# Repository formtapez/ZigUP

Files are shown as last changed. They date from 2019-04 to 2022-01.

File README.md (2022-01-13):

# ZigUP
CC2530 based multi-purpose ZigBee Relais, Switch, Sensor and Router

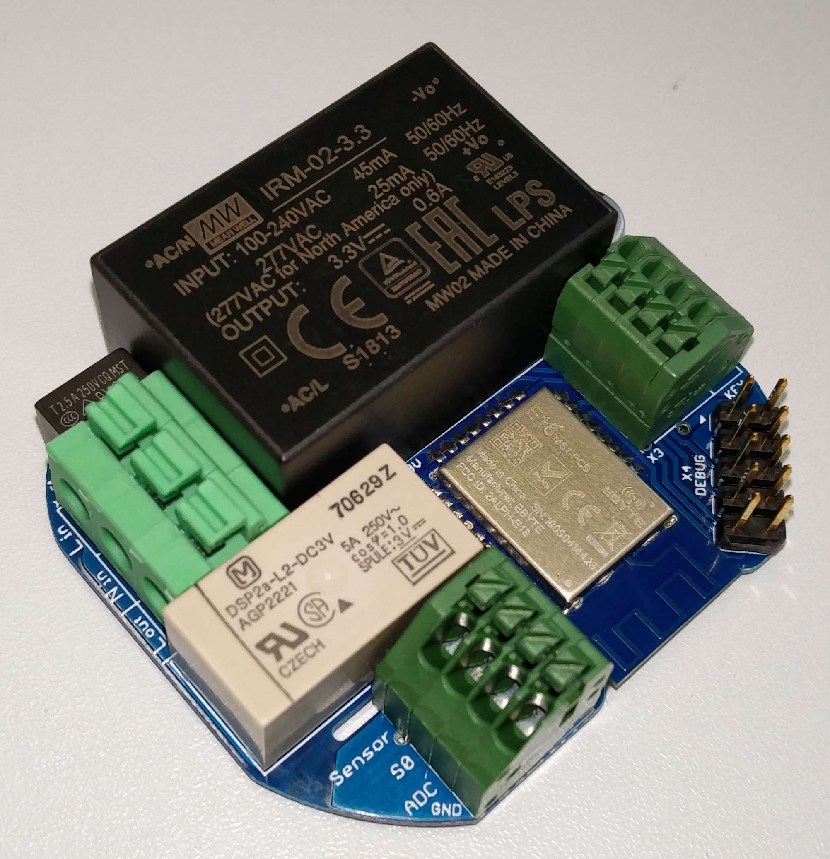
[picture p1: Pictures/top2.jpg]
Image of ZigUP board

[Bottom side](https://raw.githubusercontent.com/formtapez/ZigUP/master/Pictures/bottom.jpg)

# Features

* [Small enough to fit under a normal lightswitch](https://raw.githubusercontent.com/formtapez/ZigUP/master/Pictures/size.jpg) in an european flush-mounted box ("Unterputzdose" - That´s the UP in ZigUP)
* integrated optional ZigBee Router functionality (extends the range of all your other devices)
* Powerful bistable relais for up to 10 amps load
* 2 Inputs for switches/buttons:
	* Input "KEY" directly toggles the relais and outputs a ZigBee message
	* Input "DIG" only outputs a ZigBee message - So your coordinator can decide if the relais has to be toggled or not.
* Input for 16 digital temperature (DS18B20) and 1 humidity sensors (DHT22/AM2302) (Measurements will be reported via ZigBee)
* Input for S0-Bus impulses from power-, water- or gas-meters. Count-Value will be reported via ZigBee)
* Output for one normal LED or up to 10 WS2812B/Neopixel RGB-LEDs (controllable via ZigBee)
* Analog input to measure voltages of up to 32 Volt. (Voltage will be reported via ZigBee)
* Fully equipped debug-port to allow CC Debugger flashing and packet sniffing

# Connection diagrams

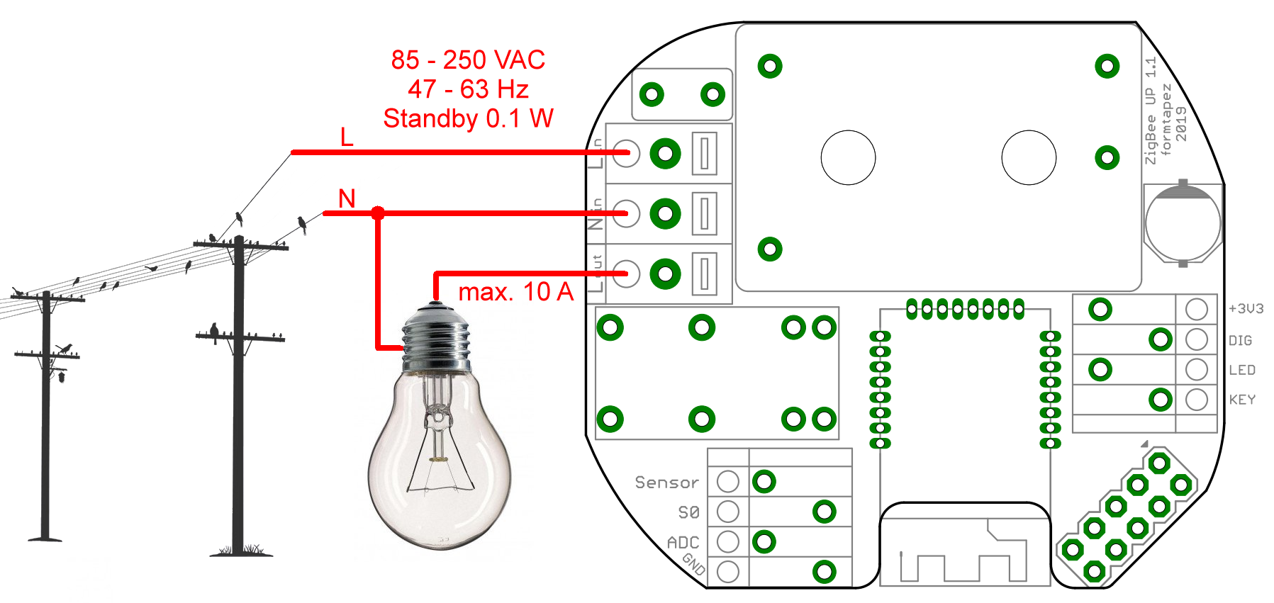
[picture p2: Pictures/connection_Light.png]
Power and Light connections

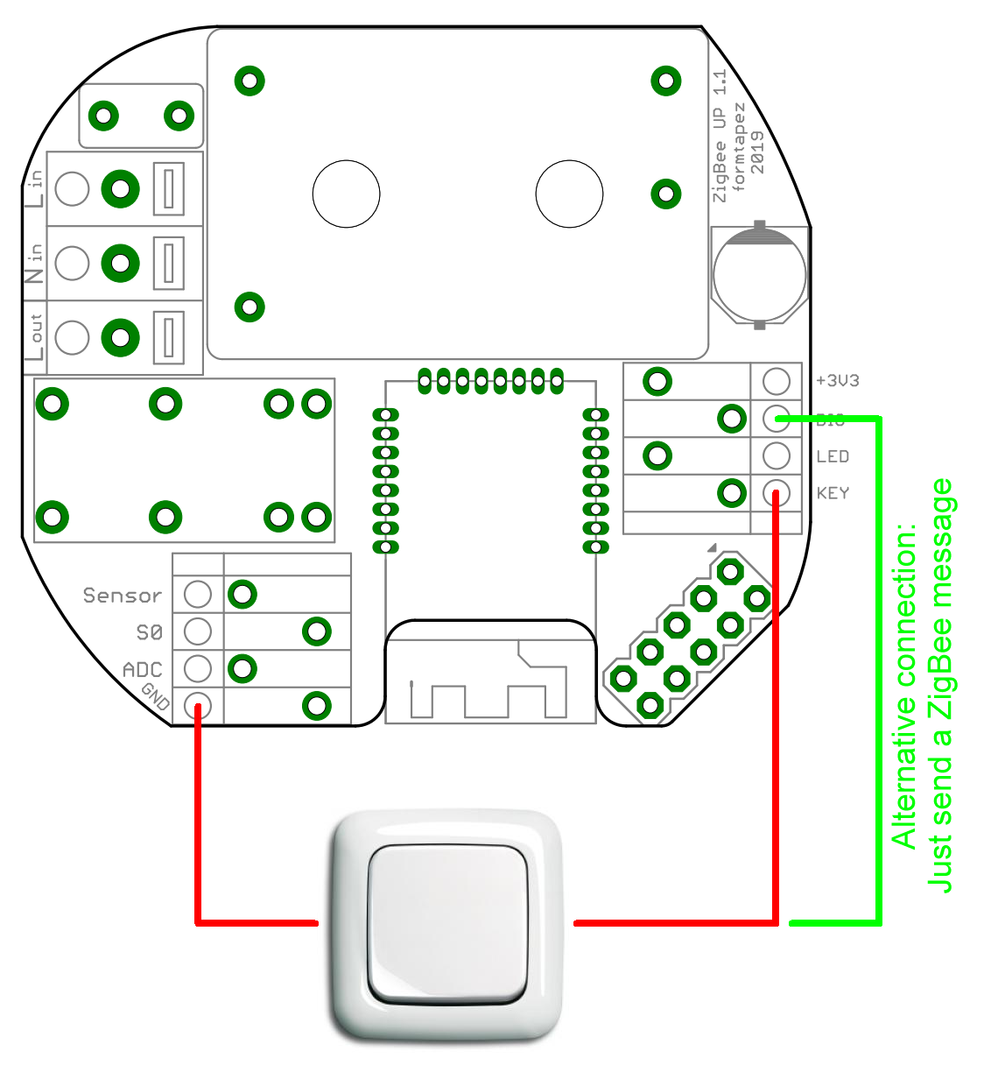
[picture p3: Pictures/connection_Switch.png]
Switch connections

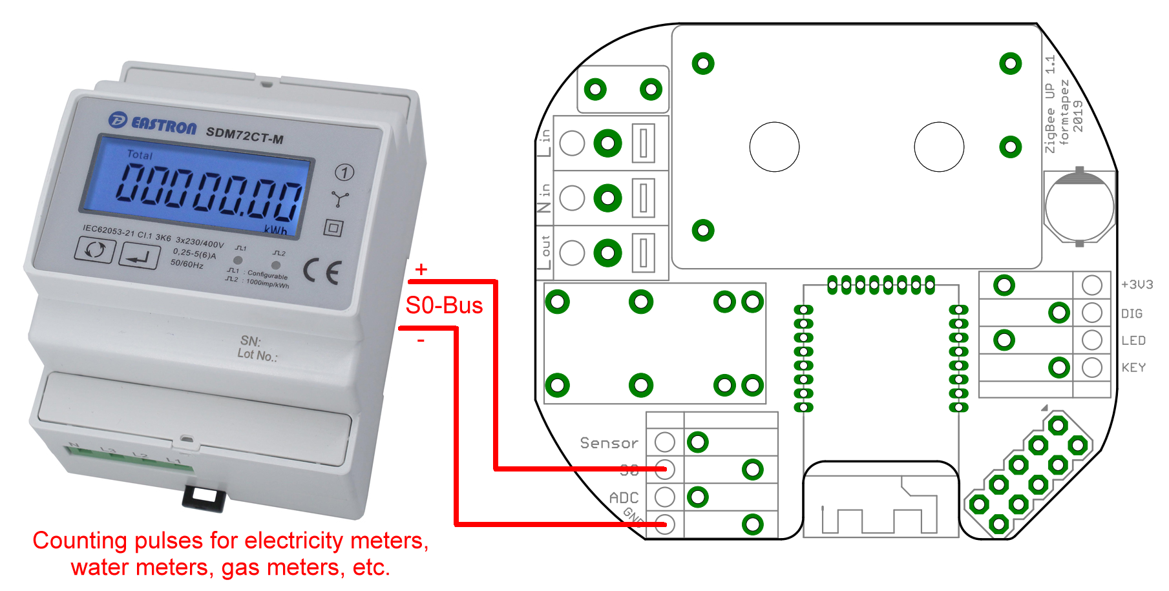
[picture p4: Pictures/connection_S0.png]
S0 connections

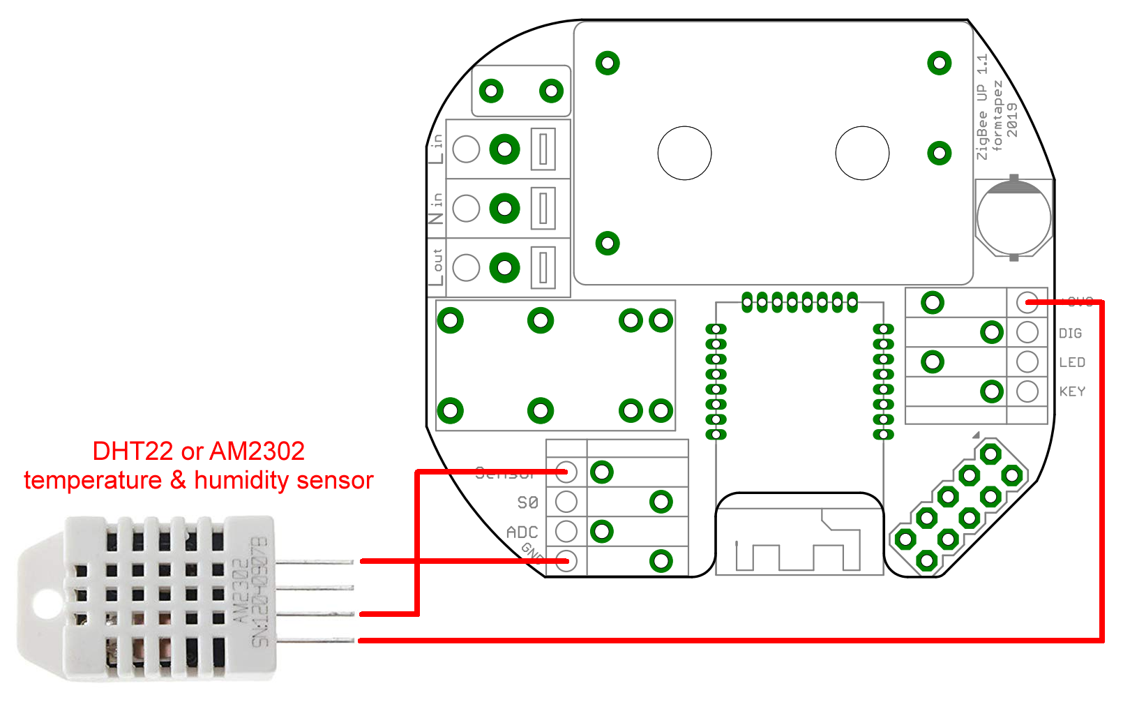
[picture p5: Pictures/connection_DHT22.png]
DHT22 connections

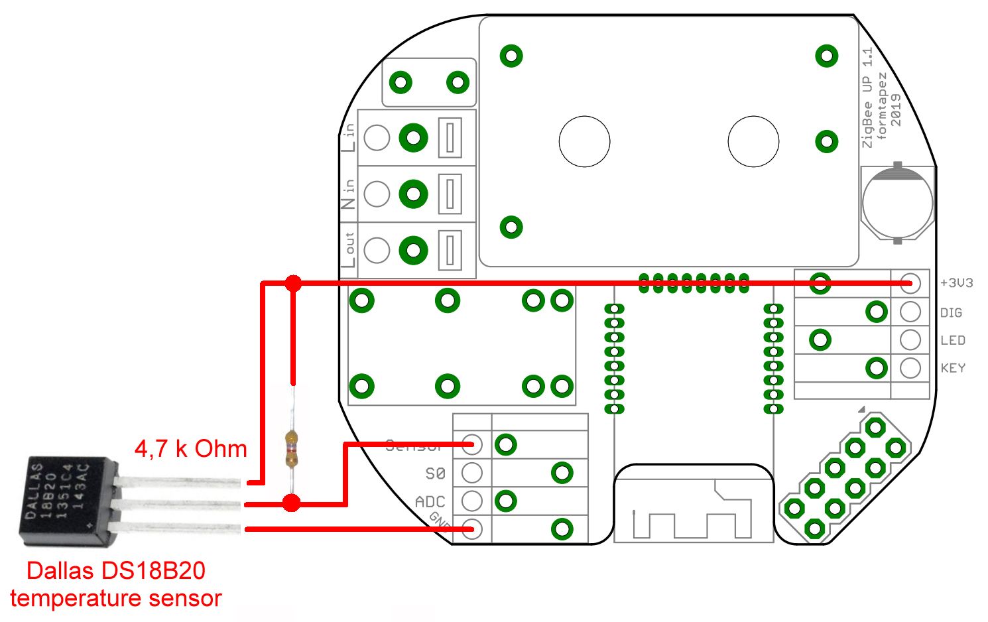
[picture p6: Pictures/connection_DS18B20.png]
DS18B20 connections

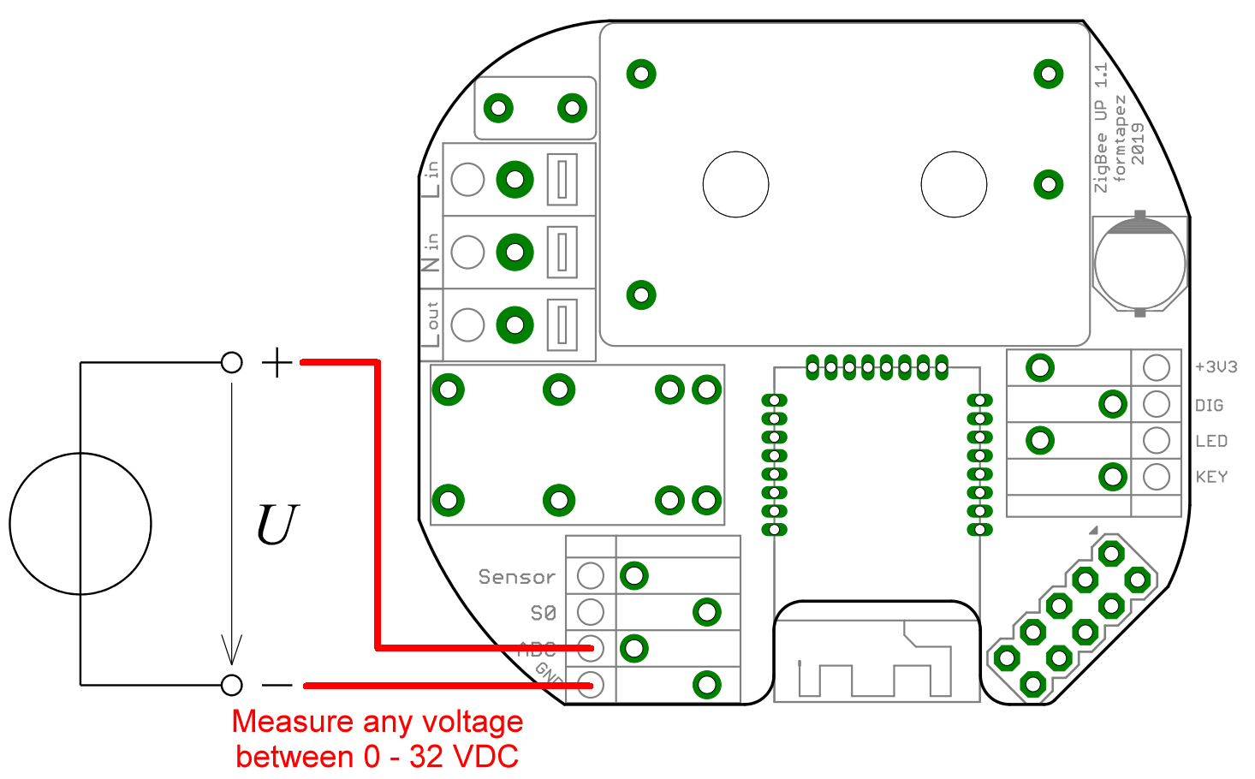
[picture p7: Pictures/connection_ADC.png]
ADC connections

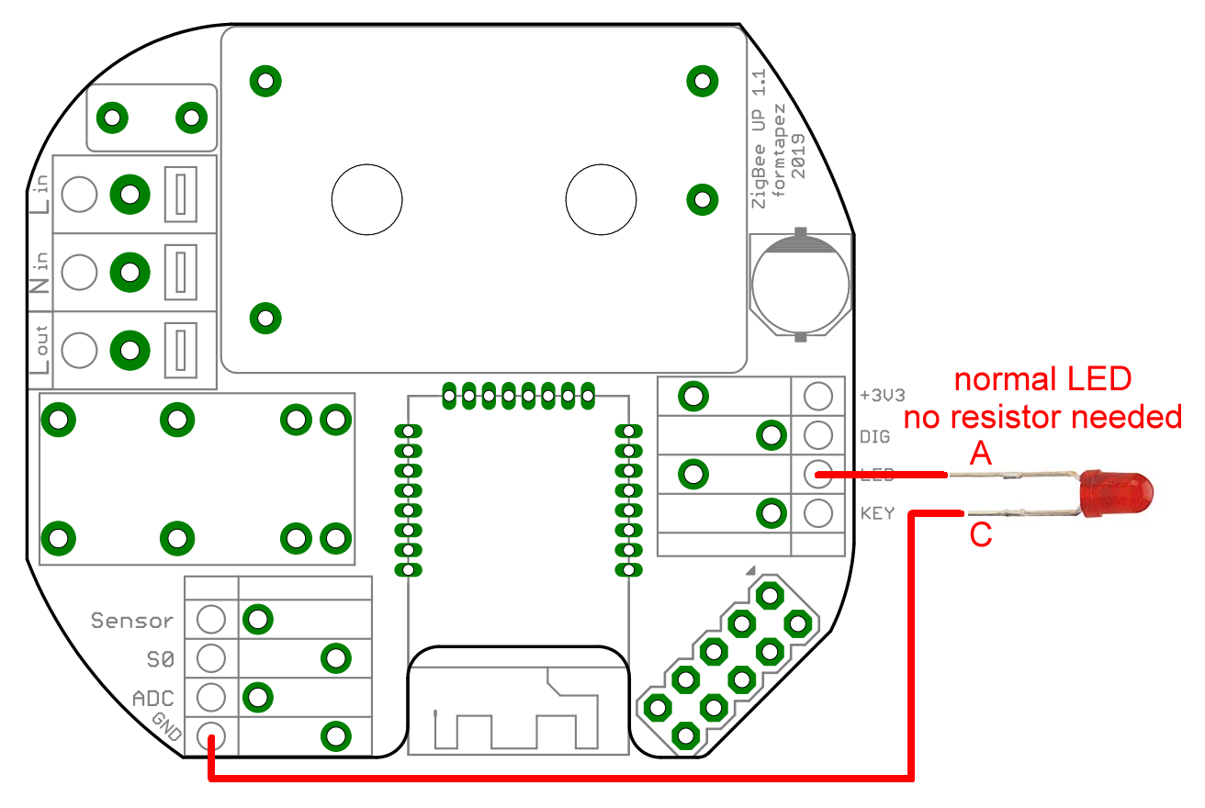
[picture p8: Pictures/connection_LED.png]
LED connections

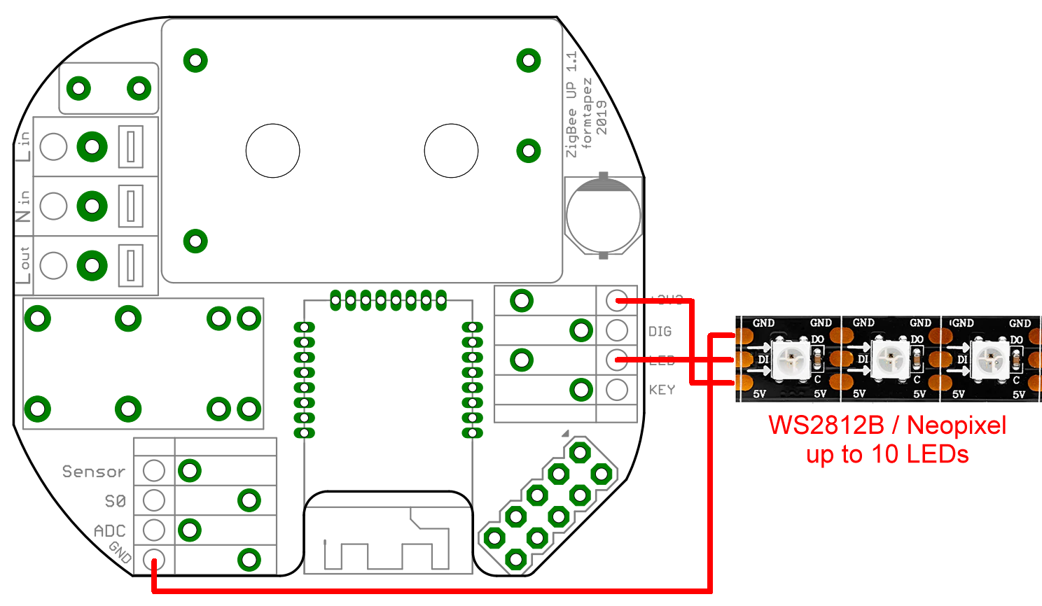
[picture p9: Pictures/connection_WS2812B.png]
WS2812B connections


# Compilation

1. Get **Z-Stack Home 1.2.2a.44539** from http://www.ti.com/tool/Z-STACK-ARCHIVE
2. Get **IAR Embedded Workbench for 8051** from https://www.iar.com/iar-embedded-workbench (you can use the free trial version for one month)
3. Clone ZigUP source to **\Projects\zstack\HomeAutomation\ZigUP\\**
4. Start **\ZigUP\CC2530DB\ZigUP.eww** to load project in IAR
5. Choose between **Router** and **EndDevice** configuration
6. Edit **\Projects\zstack\Tools\CC2530DB\f8wConfig.cfg** to select the ZigBee channel your coordinator is using.
7. Compile

# Flashing with CC Debugger
1. Get **SmartRF Flash Programmer v1.12.8 (not v2.x!)** from https://www.ti.com/tool/flash-programmer
2. Connect CC Debugger to the Debug-Port of ZigUP with an 1:1 cable.
3. Select "Program CCxxxx..." and "System-on-Chip" tab
4. Load HEX-File and perform "Erase, program and verify" action

# Packet Sniffing using CC Debugger
As an alternative usage of this board, it can be used as a ZigBee packet-sniffer in combination with the CC Debugger.
1. Get **PACKET-SNIFFER v2.18.1 (not SNIFFER-2 v1.x!)** from https://www.ti.com/tool/PACKET-SNIFFER
2. Connect CC Debugger to the Debug-Port of ZigUP with an 1:1 cable.
3. Select protocol "IEEE 802.15.4/ZigBee" and click "Start"
4. Change radio channel and click "Start"
5. Re-flash ZigUP firmware when you are done, because it was replaced by a sniffer-firmware.

# Bill of Materials (BOM)

Qty | Value | Package | Parts | URL (exemplary supplier)
:--:|:----- |:------- |:------|:------------------------
5 | 100 | R0805 | R1, R3, R5, R9, R10 | https://uk.farnell.com/multicomp/mcwr08x1000ftl/res-100r-1-0-125w-0805-thick-film/dp/2447552
1 | 1k | R0805 | R8 | https://uk.farnell.com/multicomp/mcsr08x102-jtl/res-1k-5-0-125w-0805-ceramic/dp/2074338
3 | 10k | R0805 | R2, R4, R6 | https://uk.farnell.com/multicomp/mcwr08x1002ftl/res-10k-1-0-125w-0805-thick-film/dp/2447553
1 | 27k | R0805 | R7 | https://uk.farnell.com/multicomp/mcwr08x2702ftl/res-27k-1-0-125w-thick-film/dp/2447620
2 | 100n | C0805 | C4, C5 | https://uk.farnell.com/multicomp/mcu0805r104kct/cap-0-1-f-50v-10-x7r-0805/dp/9406387
3 | 10µ | C0805 | C1, C3, C6 | https://uk.farnell.com/murata/grm21br61e106ma73l/cap-10-f-25v-20-x5r-0805/dp/2611941
1 | 220µ/6V3/EEEFK0J221P | PANASONIC_D | C2 | https://uk.farnell.com/panasonic/eeefk0j221p/cap-220-f-6-3v-radial-smd/dp/1850086
8 | 4148 | 1206 | D1 - D8 | https://uk.farnell.com/taiwan-semiconductor/ts4148-rxg/diode-small-signal-75v-0-15a-1206/dp/2708388
2 | IRFML8244 | SOT23 | T1, T2 | https://uk.farnell.com/infineon/irfml8244trpbf/mosfet-n-ch-25v-5-7a-sot23/dp/1857298
1 | IRM-02-3.3 | IRM-02 | IC1 | https://uk.farnell.com/mean-well/irm-02-3-3/power-supply-ac-dc-3-3v-0-6a/dp/2815480
1 | CC2530 | E18-MS1-PCB | IC2 | https://www.aliexpress.com/item/-/32803052003.html
1 | DSP2A-L2-DC3V | DSP2A-L2 | K1 | https://uk.farnell.com/panasonic-electric-works/dsp2a-l2-dc3v/relay-dpst-no-250vac-30vdc-5a/dp/2095635
1 | MST 2.5A 250V | MST | F1 | https://uk.farnell.com/multicomp/mst-2-5a-250v/fuse-radial-slow-blow-2-5a/dp/1566104
1 | Phoenix 1792876 | PTS-3 | X1 | https://uk.farnell.com/phoenix-contact/1792876/terminal-block-wire-to-brd-3pos/dp/2072378
2 | TE 1-2834021-4 | MSC4 | X2, X3 | https://uk.farnell.com/te-connectivity/1-2834021-4/tb-wire-to-board-4pos-26-20awg/dp/2610379
1 | DEBUG | MA05-2 | X4 | https://uk.farnell.com/amphenol-icc-fci/67997-210hlf/connector-header-10pos-2row-2/dp/2886080
1 | PCB | FR4 | all | Use [Gerber files](https://github.com/formtapez/ZigUP/tree/master/Layout/Gerber) or contact me if you need a bare PCB

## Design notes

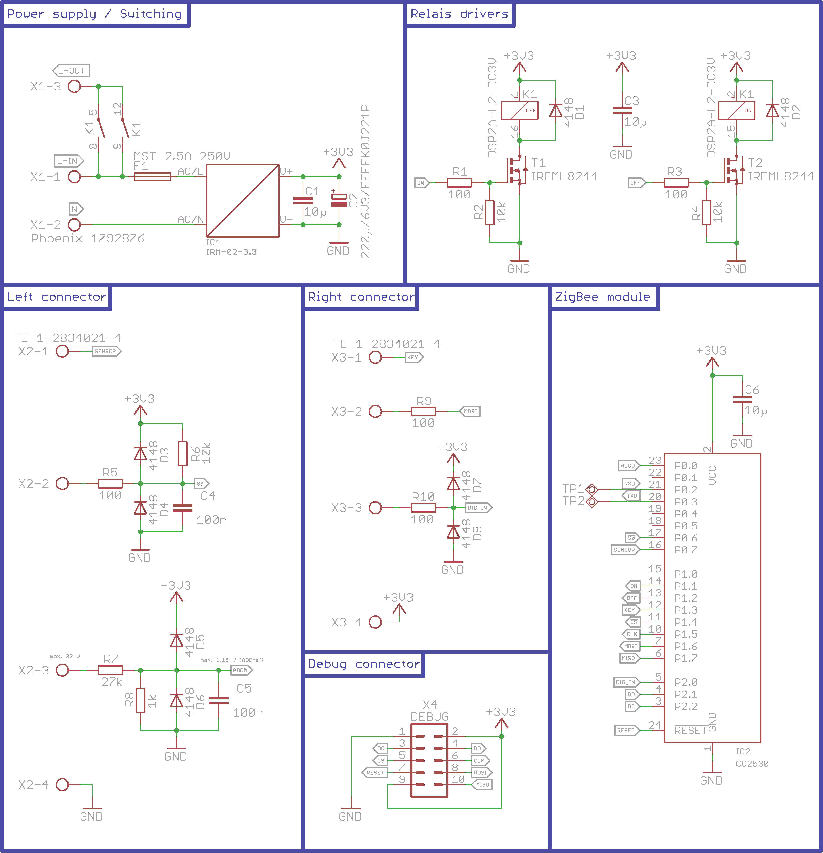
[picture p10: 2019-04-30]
Layout/Images/schematic.png

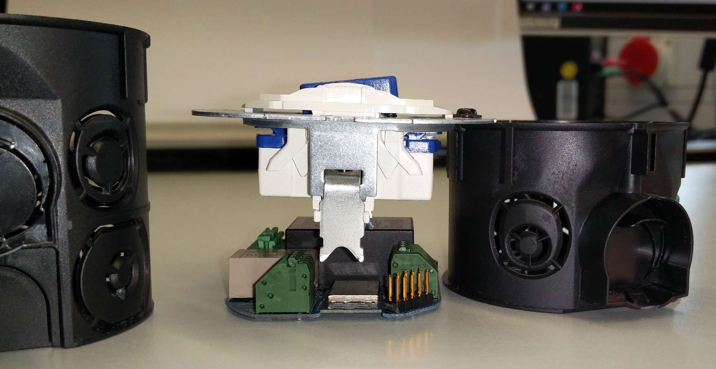
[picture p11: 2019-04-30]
Pictures/size.jpg

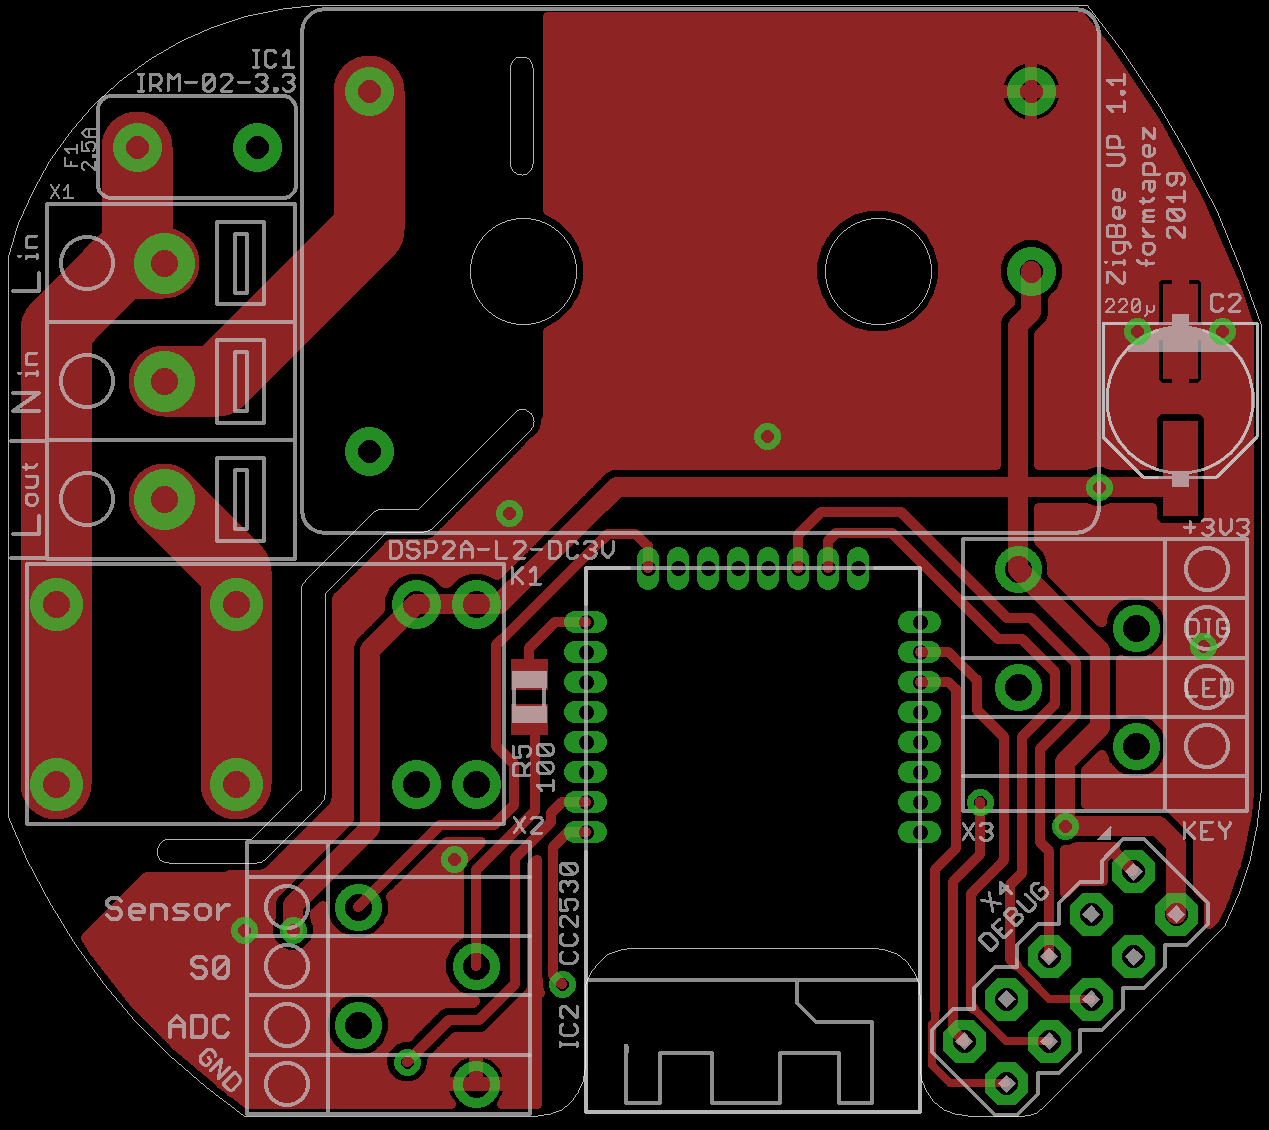
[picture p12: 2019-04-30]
Layout/Images/top.png

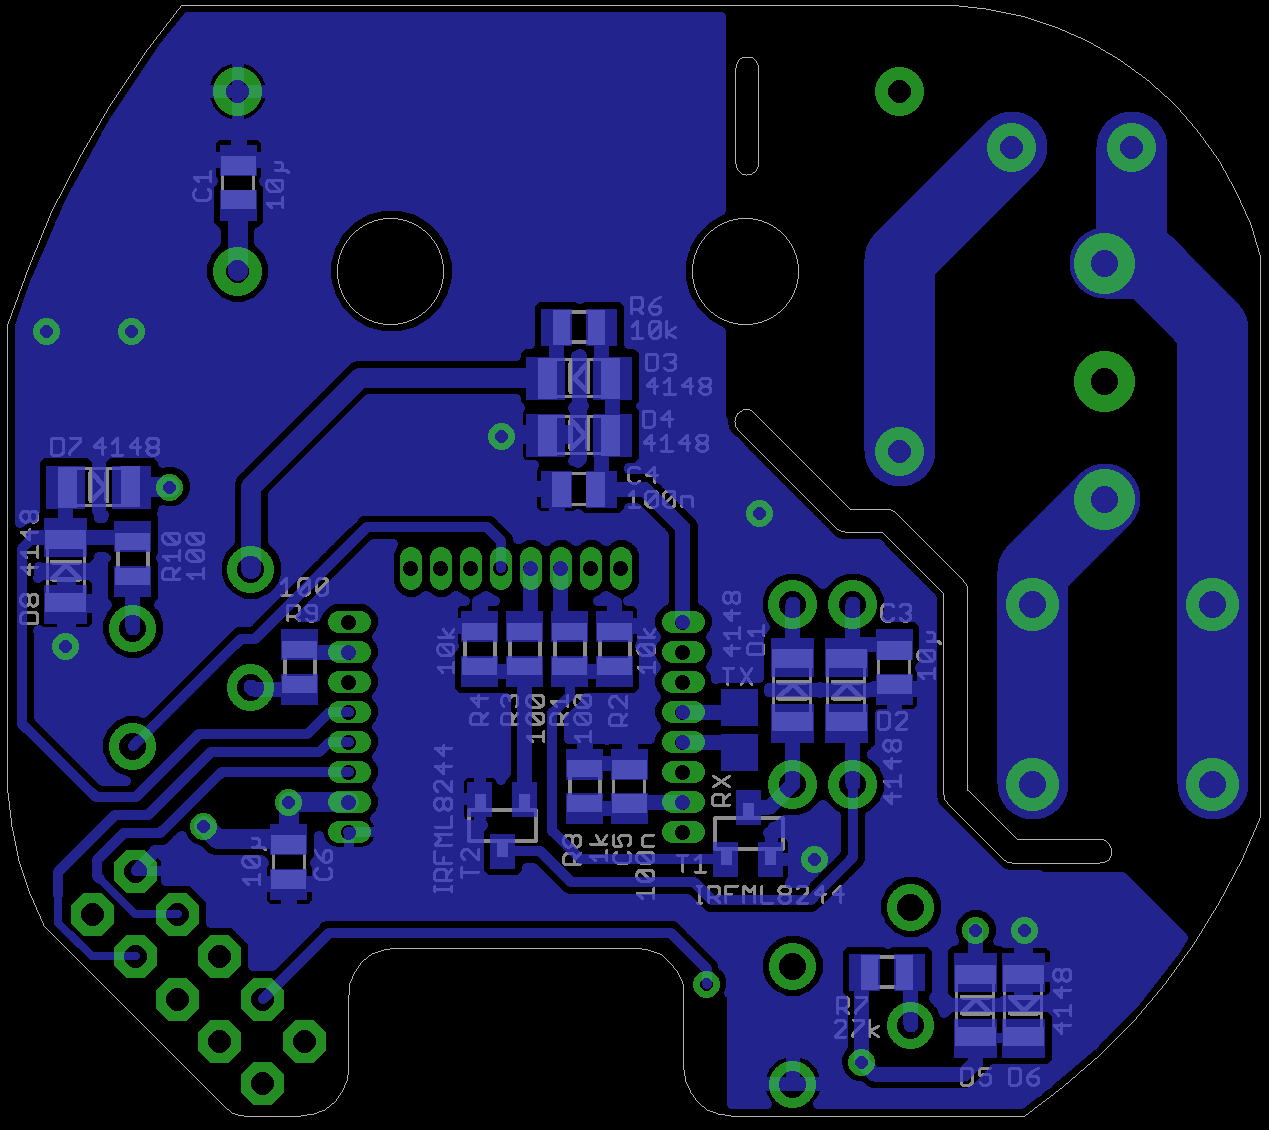
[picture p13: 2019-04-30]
Layout/Images/bottom.png

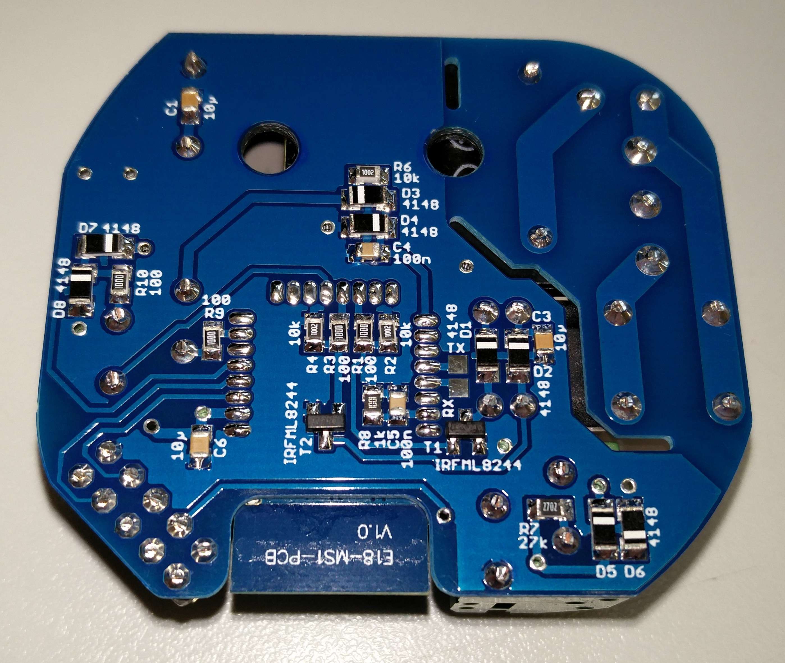
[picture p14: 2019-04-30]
Pictures/bottom.jpg

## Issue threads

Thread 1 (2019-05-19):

Where to get?

ryanbeaton, 2019-05-19:
Brilliant project!
Where to get hardware?
Will they be sold assembled?

formtapez, 2019-05-19:
Hi.
I'm not selling the hardware but you can get bare PCBs from me if you want to build it yourself.
I've added a [Bill of materials](https://github.com/formtapez/ZigUP#bill-of-materials-bom) to the end of the README.md file where you can find sellers for every component and contact info to get bare PCBs.

ryanbeaton, 2019-05-23:
Thanks
I’m not a that proficient at soldering so it’s not for me unfortunately.
If you do start selling them let me know.

h4nc, 2019-07-16:
Hi,

very interessting product. It's like a Zigbee Allrounder.

I have some soldering skills and I'm considering making some of these.

I already offer ready2use zigbee2mqtt sticks.

See https://community.home-assistant.io/t/buy-a-ready2use-zigbee2mqtt-stick-flashed-antenna-mod-and-printed-case/111743

@formtapez Would you be fine with me offering these? Currently I cannot tell how much time it would take me to make one of these, so maybe it would get to expensive for users anyway.

formtapez, 2019-07-16:
@h4nc sure, sell them if you like. Let me know when you need PCBs :)
But maybe you should wait some time for a cost-reduced version mentioned in #3

h4nc, 2019-07-16:
Thank you. A cheaper version would be great (or necessary to make it interessting for people). I will probably make some suggestions in that other issue.

aryehassbian, 2020-09-13:
> Hi.
> I'm not selling the hardware but you can get bare PCBs from me if you want to build it yourself.
> I've added a [Bill of materials](https://github.com/formtapez/ZigUP#bill-of-materials-bom) to the end of the README.md file where you can find sellers for every component and contact info to get bare PCBs.

That looks interesting..
Do you have Gerber file for download?
Thanks

formtapez, 2020-09-13:
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

Yes, check out https://github.com/formtapez/ZigUP/tree/master/Layout/Gerber

darekhome, 2020-12-25:
Hi - possible to buy somewhere the PCB with at least 'smd' parts assembled...?

Closed 2020-01-15.

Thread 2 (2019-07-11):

It is perfect

freenetwork, 2019-07-11:
You have a great project. However, I wanted to learn how to program the TI CC2530 myself. Tell me how did you study? Very heavy entry.

freenetwork, 2019-07-11:
This relay Can it be attached to a conbee?

formtapez, 2019-07-11:
For flashing you can use a "CC Debugger" device. Described here: https://www.zigbee2mqtt.io/getting_started/flashing_the_cc2531.html
Or you can use an Arduino or Raspberry Pi:
https://www.zigbee2mqtt.io/information/alternative_flashing_methods.html

I don't know the "Conbee" device, but it seems it was build to pair with custom devices. So i would assume it should work.

Closed 2019-08-29.

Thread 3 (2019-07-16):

Alternative/Cheaper components

sebastianhodapp, 2019-07-16:
Dear @formtapez

first of all: Kudos for this masterpiece of work! This versatile device looks like a perfect fit for so many possible applications!

When calculating and planning to build a batch myself, it looks like the relay and the PSU are really cost drivers. Have you had a look into alternative components?

For the PSU the HLK-PM03 could be a replacement with the same form factor, but less than 2,5$: https://www.mikrocontroller.net/attachment/349613/HLK-PM03.pdf

For the relay, I haven't found one wit the same dimensions (yet), but if the jqc3f-03vdc-c (https://voron.ua/files/pdf/relay/JQC-3F(T73).pdf) could be squeezed on the board, it would be a killer (from pricing perspective with <0,5$)

BR,
Sebastian

formtapez, 2019-07-16:
Hi,
you are right, these two components are really not cheap.

I chose the Meanwell power supply for safety reasons. For something which is on mains 24/7 even when nobody is at home, i really dont like to have such HiLink module. But a dual-footprint on the pcb to still have the option would be a smarter idea.

The relay choice was not very clever, because i wanted a bistable one to safe standby-power. This in combination with only 3,3 Volt and a high switching current limited the selection possibilities on the market and drove the price up. When you try to squeeze another relais on the boards, you should take a bistable relais, too. For a normal monostable relais you have to patch the firmware.

I will make a improved board layout in some time in which these points get cleared.

h4nc, 2019-07-16:
Would be great to make it as cheap as possible (while keeping it safe of course).

So first it would lower the cost if we could use parts that are available at aliexpress (no shipping cost and cheap prices). Most of the SMD are available there but I don't know if the the cable sockets are available too. The sonoff basic is a very low cost product. Maybe you use parts they are using (relay, power supply, should be cheap and save).

Another sugestions is to use the same pinheader as the CC2531 Sticks use. It's smaller and most zigbee2mqtt flashers have that cable.
https://de.aliexpress.com/item/32972376101.html?spm=a2g0s.9042311.0.0.27424c4dKMNl5m

I hope I can get back to you when I have more ideas. Those are only suggestions.

Thanks!

h4nc, 2019-07-16:
Another idea would be to make a second version that is able to dimm lights.

Or maybe it’s possible to include that in one version. So it’s able to only switch on/off or dimmable.
There are Tuya dimmers out there that could help finding the right parts for that.

sebastianhodapp, 2019-07-17:
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

As I would only install them into some garden lights, I wouldn't be concerned. But inside at home, makes totally sense.

> The relay choice was not very clever, because i wanted a bistable one to safe standby-power. This in combination with only 3,3 Volt and a high switching current limited the selection possibilities on the market and drove the price up. When you try to squeeze another relais on the boards, you should take a bistable relais, too. For a normal monostable relais you have to patch the firmware.

I must admit, I missed that detail in the datasheet. I like your design now even more, knowing that you though even about standby-power! But true. Limits the available products significantly. I'll keep an eye open.

> I will make a improved board layout in some time in which these points get cleared.

Wow, thanks!

eddso, 2019-08-09:
First of all, very nice project, i like it, great work.
Here my suggestion for cheaper component relay:
https://lcsc.com/product-detail/Relays_HF163F-L-3-HL2T_C140724.html?currency=EUR
https://german.alibaba.com/product-detail/HF163F-L-3-HL2T-Pushbutton-Switches-60829718344.html

formtapez, 2019-08-29:
I like your second single-coil relais. It is cheap and small (the first one is too high if you want to install the board behind a wallswitch).
But that relais only has switching capacity of up to 60 watt - That can be too weak if you still have some lightbulbs somewhere.

h4nc, 2019-09-10:
@formtapez are you still planning to do a second version with cheaper components?

formtapez, 2019-09-11:
@h4nc Yes, but it is not very high on my priority list :(

martcs, 2019-12-10:
@formtapez do you still offer ZigUp pcb?  If yes than what cost it?

formtapez, 2019-12-10:
@martcs yes. Use contact-info in last line of [README.md](https://github.com/formtapez/ZigUP/blob/master/README.md) and tell me destination country and amount of PCBs, so i can calculate a price.

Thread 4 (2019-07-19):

illuminance sensor

anshgh, 2019-07-19:
Hi
Can I make a light sensor (illumination) with a BH1750?

formtapez, 2019-07-19:
The processor doesnt have a TWI interface, so its not possible.
But you can use an analog sensor like a photoresistor or solar-cell on the analog-input pin.

anshgh, 2019-07-19:
Tanks.
I need high resolution illuminance. Because my sensor Aqara Motion Sensor gives a maximum of 1000 Lx and in cloudy and sunny weather.
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
Do you know the illuminance sensor with WTI support?

anshgh, 2019-07-22:
Which pins of the CC2530 (P00-P22) correspond to the pins on your board (Sensor, S0, ADC, DIG, LED, KEY)?

formtapez, 2019-07-22:
Just have a look in the [schematic](https://raw.githubusercontent.com/formtapez/ZigUP/master/Layout/Images/schematic.png).

anshgh, 2019-07-22:
Tanks.
Can I buy such a module on Aliexpress?
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

anshgh, 2019-07-23:
or - https://ru.aliexpress.com/item/32982000600.html

formtapez, 2019-07-23:
These are no illumination sensors. But if you want to measure rotation angle, you can use them.

anshgh, 2019-07-23:
Yes. I know. This is a variable resistor to replace (not solder) the element X2-3 to ADC0. https://user-images.githubusercontent.com/8523569/61642187-2a431280-aca9-11e9-967b-9c66f99e5a8b.png

I want to use the TEMP6000 light sensor. He is 5 volt. But in your circuit to ADC0 you need 1.15 volts. Therefore, I want to use a variable resistor (links above) to connect the TEMP6000.

formtapez, 2019-07-23:
I dont think that works. The current is too low to drive the ADC. You need an active component there.

anshgh, 2019-07-23:
Why? It works for me on esp8266.

anshgh, 2019-07-23:
Can you help turn on the deep sleep mode for the CC2530 for 2 minutes in your firmware?

anshgh, 2019-07-26:
> The processor doesnt have a TWI interface, so its not possible.
> But you can use an analog sensor like a photoresistor or solar-cell on the analog-input pin.

https://e2e.ti.com/support/wireless-connectivity/zigbee-and-thread/f/158/p/824148/3049477#3049477

anshgh, 2019-08-12:
> The processor doesnt have a TWI interface, so its not possible.
> But you can use an analog sensor like a photoresistor or solar-cell on the analog-input pin.

I want to use a TEMP6000 sensor.
How often will data from analog sensors be transmitted?
Can I change this time?

formtapez, 2019-08-12:
You can change the reporting interval (default: 30s) here:
https://github.com/formtapez/ZigUP/blob/ec3112c4933cfd9b377bc32b3dd97cde0bd6086c/src/ZigUP/Source/zcl_zigup.c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

anshgh, 2019-08-14:
What is **adc_volt":2.259**? I connected TEMP6000 3.3v.
 zigbee2mqtt:info 8/14/2019, 3:16:25 PM MQTT publish: topic 'zigbee2mqtt/0x00124b001d6663ed', payload '{"state":"OFF","cpu_temperature":24.48,"external_temperature":null,"external_humidity":null,"s0_counts":0,"adc_volt":2.259,"dig_input":1,"reason":"timer","linkquality":134}'

formtapez, 2019-08-14:
that seems pretty correct for me.
you can measure up to 32 volt due to that resistor-divider at the input.

anshgh, 2019-08-20:
What you need to enable sleep mode (PM2).
"**You can define POWER_SAVING in project predefined symbols to enable it. After you define POWER_SAVING, CC2530 will enter sleeping mode automatically when there’s nothing in osal task queue.**"
Enable a compile option, del an "x" at the left edge of the line or add POWER_SAVING.

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

Awakening interval can be configured in the file zcl_zigup.c :
`#define ZIGUP_REPORTING_INTERVAL 120000 (120sec)`

Other than report interval, polling rate would wake up device every second by default.
You can change polling rate by changing -DPOLL_RATE in f8wconfig.cfg.

anshgh, 2019-09-23:
I also changed the code in zcl_zigup.c to turn off the voltage of the TEMP6000 sensor during sleep mode.
I connected TEMP6000 to 3.3v = P1.6 and data = P0.0
added:
`    // update measurements
    LED(1);
    _delay_ms(1000);
    Measure_QuickStuff();
    Measure_Sensor();
    LED(0);`

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

commented:
`    //LED(1);`
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

Closed 2019-08-14.

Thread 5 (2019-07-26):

PWM Support ?

michaelslobodskih, 2019-07-26:
Is it possible to add 2 x channel PWM support to firmware ?

formtapez, 2019-07-29:
Technically, that's possible.

https://github.com/formtapez/ZigUP/blob/master/Datasheets/CC2530%20User%20Guide.pdf
Look at table on page 81 to find a pin for a timer compare output pin, which was unused before.

michaelslobodskih, 2019-07-29:
Nice, so can u add pwm support to your firmware ?

formtapez, 2019-07-29:
I don't know that yet.
Do you have a good use-case for that? What do you want to control, and how?

michaelslobodskih, 2019-07-29:
I have led lamp controller by rc protocol . Inside this lamp there is one little pcb with 4 pins ( +,- , A, B). Channel A & B is pwm , 0-3.3v.

I installed esp8266 and all works fine with additional power supply (AC to DC 3.3 500mah).

And i have iobroker smart home  with ~ 10 zigbee devices.

So i'm intresting to replace esp8266 & power supply (is overhead for this project) with only 1 module based on cc253x.

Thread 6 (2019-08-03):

Multiple ds18b20 sensors

prelude0000, 2019-08-03:
Hello,

I added support for multiple (16 currently) 1-wire temperature sensor in this great code. It's work's fine but before i can make a merge request i need to understand how to inform zigbee2mqtt that devise have multiple sensors.

I can add use the same idea of how current sensors/peripherals are defined in zcl_zigup.c but it causes a problem when a new sensor is added and sensor order will be chances

Example there is 3 sensor and zigup sending to zigbee2mqtt following message:
 '{
"state":"OFF",
"cpu_temperature":23.98,
"external_temperature_1":21.4, // device 4D000004D0DC8328
"external_temperature_1":22.4, // device B1000004D01FBF28
"external_temperature_3":23.4, // device C000004D03CA328
"external_temperature_4":-1000,
"external_temperature_5":-1000,
...
"external_temperature_16":-1000,
"external_humidity":null,
"s0_counts":0,
"adc_volt":32.354,
"dig_input":1,
"reason":"timer",
"linkquality":23
}'

and when we add one new sensor (4 total) then important part would be:
"external_temperature_1":21.4, // device 4D000004D0DC8328
"external_temperature_2":24.4, // device A1000004D05ABF28
"external_temperature_3":22.4, // device B1000004D01FBF28
"external_temperature_4":23.4, // device C000004D03CA328
"external_temperature_5":-1000,

so sensor order what you see in zigbee2mqtt is mixed (old sensor_2 is now sensor 3)

One way to solve this is to send sensor id and temperature at the same time like this:
"4D000004D0DC8328":21.4,
"B1000004D01FBF28":22.4,

and if zigbee2mqtt do not support dynamically added devices then send dummy code for sensor what aren't connected like "0000000000000000":-1000.

As you see, i don't really know how to proceed and i would appreciate every guide/hint what you can give me to make code nice and compatible with zigbee2mqtt philosophy.

formtapez, 2019-08-29:
Looking at your pullrequest #9 it seems you found a solution meanwhile. So i'll close here.
(I'll review your PR in the next few days)

Closed 2019-08-29.

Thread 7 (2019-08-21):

Improve detail on how to flash HEX files

daparix, 2019-08-21:
I just build/soldered my first unit, and running following issues:
- Not sure of the polarity of the 10-pin programming connector. I understood it should be with red wire (pin 1) on the far side of the RF board (close to the connector of KEY/LED/DIG).

- I had to file one corner of the connector of the CC debugger cable before I could make it fit. Is this normal?

- It would be nice if there is some guideline to flash units with a default HEX file (I found it in another repository, but would be good to have default hex files here so compiling is not needed).

- As a bonus, would be great to have a guide to flash them using Ubuntu (i.e with cctool). I have found some bits of info, but as the default Windows flashing does not work, I do not dare to try a Linux flash yet.

PD: Not really in the main request as this part is not generic, but I can not flash the hex and would need some help:
The CC debugger shows red led when I do not connect the ZigUP and SmartRF Studio detects it right. If I plug the CC debugger with ZigUP connected, led shows off (and USB does not detect the CC debugger). Do I need to power ZigUP as well to 220V or it maybe some problem with my soldering - I just took a snapshop if someone can confirm it is right?

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

daparix, 2019-08-21:
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

daparix, 2019-08-21:
None: Just realized the HEX files can be got from "Releases" tab, but I meant to have the HEX files as part of the source tree as well for those users that are not very expert with GitHub

formtapez, 2019-08-21:
Hi, please do not connect 220 Volts in this state - It is way too dangerous.
Powering via CC-Debugger is totally okay for programming.

It seems you have a short somewhere between GND and +3V3, when your Debugger-LED went off when plugging in. Can you measure resistance between this two signales?

Your polarity of the connector is right, and yes, it is very tight to the connector nearby.

daparix, 2019-08-22:
thanks for all the feedback!

indeed I have a short between 3.3V and GND. I tried visually and resoldered a couple of components, but I have still not fixed it, so will need to allocate more time. will come back as I progress on this, maybe I try a second unit mount (step by step) to progress on this, as I guess will be quicker/easier than finding the wrong solder or component in my first unit.

great work done by you!

daparix, 2019-09-09:
Sorry to have delayed so much, I have too many projects in queue!!.
Built a second unit checking carefully each component soldering as I mounted them and I got a working one. Resistance between 3.3V and GND is around 4.5Kohm.

This one properly connects via CC_Debugger and I got a nice green led light, so ready to be programmed.

Many thanks!

Closed 2019-08-29.

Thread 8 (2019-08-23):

GB2530 - Different Module

YeisonCL, 2019-08-23:
Hi,

First of all, kudos for this project, it is really incredible!

I have a quick question.

Is it possible to use a different module for this project? I noticed you used E18-MS1-PCB module for this project. I have a GB2530 module: [GB2530 Module](http://www.gban.cn/en/product_show.asp?id=47)

This module includes the CC2530 + RFX2401, can I use this module instead of  E18-MS1-PCB?

Thanks!

formtapez, 2019-08-23:
Hi,
this module does not fit on the board, the footprint and pinout is different and you would have to include the controlling of the integrated RF-amplifier into the software.

Closed 2019-08-23.

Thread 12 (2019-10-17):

Reset

copystring, 2019-10-17:
Is there a way to reset the pairing and re-pair?
I assume I have to flash this again to re-pair.
Or is there another way?

formtapez, 2019-10-18:
If you have connected a button to the "key" input, you can press it for 5 seconds to initiate re-pairing.
Also when you turn off you coordinator so ZigUp is loosing connection, it enters re-pairing mode.

copystring, 2019-10-18:
OK. Hold the button seems to initiate re-pairing. The relay clicks off and on quickly. Assuming it worked it does not re-enter my network. I have changed the  channel of my network to 13 and changed the pan_id as well.
Does that matter?

formtapez, 2019-10-18:
Depends on which firmware you flashed. The precompiled hex files from the Release-section is fixed to channel 25.

copystring, 2019-10-18:
Right. Changed back to channel 11. It works now with the precompiled firmware. Why do you say it is channel 25? It is channel 11. Am I missing something here?

formtapez, 2019-10-18:
With "precompiled firmware" i mean the hex-files from the "release" section here on github.
I compiled them with
`-DDEFAULT_CHANLIST=0x02000000  // 25 - 0x19`
in zstack\Tools\CC2530DB\f8wConfig.cfg

The default there is channel 11. Did you compiled it yourself?

copystring, 2019-10-18:
Nope. I am using the precompiled version. Could not be bothered to install all the tools.

Closed 2019-10-19.

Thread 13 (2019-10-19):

Cannot read property '41368' of undefined

copystring, 2019-10-19:
Not sure if this is an issue with ZigUP or z2m. Let me know if it does not belong here.

I am getting a lot of this:

```
Oct 19 11:17:12 raspberrypi npm[9723]: zigbee2mqtt:error 2019-10-19T09:17:12: Failed to call 'DeviceReceive' 'onZigbeeEvent' (TypeError: Cannot read property '41368' of undefined
Oct 19 11:17:12 raspberrypi npm[9723]:     at Object.convert (/opt/zigbee2mqtt/node_modules/zigbee-herdsman-converters/converters/fromZigbee.js:1353:30)
Oct 19 11:17:12 raspberrypi npm[9723]:     at converters.forEach (/opt/zigbee2mqtt/lib/extension/deviceReceive.js:146:41)
Oct 19 11:17:12 raspberrypi npm[9723]:     at Array.forEach (<anonymous>)
Oct 19 11:17:12 raspberrypi npm[9723]:     at DeviceReceive.onZigbeeEvent (/opt/zigbee2mqtt/lib/extension/deviceReceive.js:144:20)
Oct 19 11:17:12 raspberrypi npm[9723]:     at Controller.callExtensionMethod (/opt/zigbee2mqtt/lib/controller.js:320:44)
Oct 19 11:17:12 raspberrypi npm[9723]:     at Controller.onZigbeeEvent (/opt/zigbee2mqtt/lib/controller.js:228:14)
Oct 19 11:17:12 raspberrypi npm[9723]:     at Zigbee.emit (events.js:198:13)
Oct 19 11:17:12 raspberrypi npm[9723]:     at Controller.herdsman.on (/opt/zigbee2mqtt/lib/zigbee.js:56:52)
Oct 19 11:17:12 raspberrypi npm[9723]:     at Controller.emit (events.js:198:13)
Oct 19 11:17:12 raspberrypi npm[9723]:     at Controller.<anonymous> (/opt/zigbee2mqtt/node_modules/zigbee-herdsman/dist/controller/controller.js:405:22))
```

Looking at the code of z2m it seems it does that with the precompiled firmware since it does not have the temp sensor connected?

formtapez, 2019-10-19:
Property '41368' is a newer way of reporting DS18B20 sensors. It is used even if you have no sensors. Support for that is merged into Zigbee2MQTT source, but it seems that it hasn't reached into the "stable" channel yet.
You can manually update this file just by replacing it:
https://github.com/Koenkk/zigbee-herdsman-converters/blob/master/converters/fromZigbee.js

copystring, 2019-10-19:
Replace it? Not sure what to replace it with. Or do you meant to delete it?

formtapez, 2019-10-19:
Replace the file from your zigbee2mqtt installation with that linked file from the zigbee2mqtt repository.

copystring, 2019-10-19:
Oh. Sorry I missunderstood.
I already have that file on my system. Using the dev version of z2m only updated it yesterday and that includes this file.

formtapez, 2019-10-19:
Hm, do you find '41368' in that file?

copystring, 2019-10-19:
Yes. It is there. This is why I am wondering what is going on :)

This is what mine looks like:

https://imgur.com/Y56lz6H

formtapez, 2019-10-19:
Ah, okay.
Sorry, i see the problem now.
I forgot to publish the new precompiled firmware which is sending that 41368 property.
Have a look at https://github.com/formtapez/ZigUP/releases

copystring, 2019-10-19:
Okay. I flashed my devices again. Now I cannot control them anymore. They do not rejoin even after resetting.

copystring, 2019-10-19:
Okay. I flashed my devices again. Now I cannot control them anymore. They do not rejoin even after resetting.

formtapez, 2019-10-19:
Deleting them from your zigbee2mqtt database-file before re-pairing helps.

copystring, 2019-10-19:
Yes. I tried this. I think it has something to do with the channel.
No idea how it worked before since you compiled it with channel 25 and I use channel 11.
Looked into compiling myself. It is a pain...
Could you make one with channel 11 as well? Surely that makes sense. That is the default channel. Most people use this one.

copystring, 2019-10-19:
Okay. I managed to compile it with channel 11 and #define ATTRID_EXT_TEMPS        41368. Re-paired the device.
The Problem remains.

copystring, 2019-10-20:
In this file: https://github.com/Koenkk/zigbee-herdsman-converters/blob/master/converters/fromZigbee.js

`Line 1353: if (msg.data.data['41368']) {`

Is that correct? Should it not be: `if (msg.data['41368']) {`?

The lines below line 1353 use msg.data instead of msg.data.data.

copystring, 2019-10-20:
Changed

`            if (msg.data.data['41368']) {
                ds18b20Id = msg.data.data['41368'].split(':')[0];
                ds18b20Value = precisionRound(msg.data.data['41368'].split(':')[1], 2);
            }`

to

`            if (msg.data['41368']) {
                ds18b20Id = msg.data['41368'].split(':')[0];
                ds18b20Value = precisionRound(msg.data['41368'].split(':')[1], 2);
            }`

It actually works fine now. Also getting a lot more readings. Like CPU temp, etc. They did not appear before.
Do you think this was the issue?

Closed 2019-10-24.

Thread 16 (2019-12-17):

Does anyone have a problem if I mount this badge and market it?

Francisk0, 2019-12-17:

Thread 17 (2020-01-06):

Question about integration with zigbee2mqtt

azh-github, 2020-01-06:
So far, all my attempts to manage have not been completely successful. Where can I find out what exactly to send to the topic "mqtt", to control the LED and WS2812 tape.
While I control only the relay, sending to the topic 'zigbee2mqtt/ZigUP1/set'  <- ON or OFF.
I see pulses on the oscilloscope at the output of turning the polarized relay on or off. It's good.
But attempts to send to ".../set/led" lead to errors in zigbee2mqtt, but simply to "set" do not give a result.
There is no information and can not find - how to.
I ask for help.
Thanks.

azh-github, 2020-01-06:
so far I have done so:
`static void zclZigUP_OnOffCB( uint8 cmd )
...
// Turn on the light
  if ( cmd == COMMAND_ON )
  {
    Relais(LIGHT_ON);
    LED(1);
  }
  // Turn off the light
  else if ( cmd == COMMAND_OFF )
  {
    Relais(LIGHT_OFF);
    LED(0);
  }
...
`
But, I need an independent LED, but I’m silent about the tape :)

formtapez, 2020-01-06:
Send "{"led":"toggle"}" (or on/off instead of toggle) to your "set" topic.

For the WS2812 tape use {"light_color":"..."} for the "set" topic.
You can use several parameter formats for that (see https://github.com/formtapez/ZigUP/blob/c14e12ebba28ea22bc18bfca1ce4d822ef75c947/zigbee-shepherd-converters/converters/toZigbee.js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 ).
Its compatible with nodered's colorpicker.

azh-github, 2020-01-06:
'Error: Cluster 'genOnOff' has no command '{led:on}'
...
'Error: Cluster 'genOnOff' has no command '{led:off}'
in zigbee2mqtt log :(

Cluster 'genOnOff' -- is right target?

azh-github, 2020-01-06:
i'm use "openHUB2" for tests

azh-github, 2020-01-06:
Error: Cluster 'genOnOff' has no command ' "{"led":"toggle"}"

formtapez, 2020-01-06:
Cluster 'genOnOff' is only used for the relais.
You dont have to care about the cluster - zigbee2mqtt chooses the right one depending of the command. Maybe your version is outdated and it doesnt know ZigUp yet?
Unfortunately i cannot say anything about openHAB2.

azh-github, 2020-01-06:
o lala!  wonderwork ... :)
1. i sent 'on' to topic 'zigbee2mqtt/ZigUP1/set/led'   -- and the LED turned on
2. i sent 'off' to topic 'zigbee2mqtt/ZigUP1/set/led'  -- and the LED turned off
(used the program 'MQTT.fx')
We continue research :)

azh-github, 2020-01-06:
It turned out the following:
The command reaches its destination when sent to the topic 'zigbee2mqtt / ZigUP1 / set / led' <- "on" or "off", but if you immediately send any second command, it fails with the diagnostics "'Error: Data request failed with error:' MAC no ack '" ... in my opinion, the 2530 controller restarts at this time.
  Diagnostics:
zigbee2mqtt:debug 2020-01-06 22:00:58: Error: Timeout - 32826 - 8 - 49 - 257 - 11 after 15000ms
...
zigbee2mqtt:info  2020-01-06 22:00:58: MQTT publish: topic 'zigbee2mqtt/bridge/log', payload '{"type":"zigbee_publish_error","message":"Publish 'set' 'led' to 'ZigUP1' failed: 'Error: Timeout - 32826 - 8 - 49 - 257 - 11 after 15000ms'","meta":{"friendly_name":"ZigUP1"}}'
--
Conclusion:
Or zigbee2mqtt of the latest version (zigbee2mqtt: '1.8.0') does not know how to work with ZigUP correctly and stands on an unrequited timer, Or there is an error in the ZigUP code (after all, the LED is controlled all the same) and the timer simply does not wait for a response from ZigUP.
--
sh-5.0$ npm version
{
  zigbee2mqtt: '1.8.0',
  npm: '6.13.4',
  ares: '1.15.0',
  brotli: '1.0.7',
  cldr: '36.0',
  icu: '65.1',
  llhttp: '2.0.1',
  modules: '79',
  napi: '5',
  nghttp2: '1.39.2',
  node: '13.5.0',
  openssl: '1.1.1d',
  tz: '2019c',
  unicode: '12.1',
  uv: '1.34.0',
  v8: '7.9.317.25-node.23',
  zlib: '1.2.11'
}

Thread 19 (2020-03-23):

Compilation problems with instructions from README

Boldie, 2020-03-23:
I got strange compilation errros not finding paths if I follow the readme.

> Clone ZigUP source to \Projects\zstack\HomeAutomation\ZigUP\

Done

> Start \ZigUP\CC2530DB\ZigUP.eww to load project in IAR

Where is this located? I tried to open it in subdirecoty src -> Strange compile errors not finding the framework. Moving sources from /src to / I got some other compile errors.

Have you some advices how to compile the stuff?

formtapez, 2020-03-24:
Copy the "src/ZigUP" folder from the git-repository to your Z-Stack installation folder so it looks like this: \Projects\zstack\HomeAutomation\ZigUP\
In that folder start CC2530DB\ZigUP.eww to load the project in IAR.
In the opened project search for f8wConfig.cfg in some of the displayed subdirectories and select the ZigBee channel your coordinator is using.

Boldie, 2020-03-24:
Ok. I managed to compile the code. I uploaded the code to my evalboard. Unfortunately the device did not join my network. But it seems to behave like the other sample applications form TI with my zigbee2mqtt coordinator (checked channel and also added network default key to project). I think I have to wait till my ordered CC2531 device will come to sniff the network to check where the problem is.

tonipetrovic, 2020-05-25:
Dear @formtapez ,

I did it as you mentioned, but IAR cannot find f8wConfig.cfg. It reports that **contains incorrect path.

Regards,
Toni

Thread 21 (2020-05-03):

Reporting interval too high

IVI053, 2020-05-03:
At the moment it is set to 30 seconds. This leads to much unnecessary messages being sent when using multiple ZigUP devices.

I would suggest to set it to a more reasonable value of 300 seconds or even 1800.

antonteplov, 2020-10-06:
@IVI053  Try to change this  (ms):
https://github.com/formtapez/ZigUP/blob/c14e12ebba28ea22bc18bfca1ce4d822ef75c947/src/ZigUP/Source/zcl_zigup.c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

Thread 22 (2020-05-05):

Factory reset not working

IVI053, 2020-05-05:
When triggering dig for Mode than 5 seconds IT should factory reset the device. At least if I understand the interrupt handler correctly and mit miss something.
Problem is - it doesn't.
Can someone confirm or contradict this?

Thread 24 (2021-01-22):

Firmware router kick out after join

xadieu01, 2021-01-22:
I flash firmware router zigup 1.1.3 on cc2530 but when i join device to coordinator 3.0, it kick out the network after join and fail lqi. Can you fix it for me?
Thank you!

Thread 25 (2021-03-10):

Up for group order ?

kds69, 2021-03-10:
Dears,
Since I am not competent to solder SMTs I have take a quote for 5x ZigUp assembled by supplier.
The ticket price is $80 by item +shipping cost from France.
Just let me know if you are interested.

codingcatgirl, 2021-03-10:
Soldering the SMD components is pretty easy. I'm by no means very experienced at soldering but with a few online tutorials it was fairly easy to do. It drops the price to <20$ per item.

codingcatgirl, 2021-03-10:
Just to add: If you are willing to pay $80 (where are you even ordering? JLCPCB has to be cheaper) you might as well order a comemrcially available product similar to ZigUP for less money, giving you the added benefit of CE compliance etc.

gsieben, 2021-03-10:
This is far from an acceptable and fair price. The price is usurious.

kds69, 2021-03-10:
> Soldering the SMD components is pretty easy. I'm by no means very experienced at soldering but with a few online tutorials it was fairly easy to do. It drops the price to <20$ per item.

Really ? Will you assemble and solder it for me please for less than $20?
Just the one of the component is already $14... glad to read rest is $6 including PCB.

kds69, 2021-03-10:
« Where are you even ordering »? Please pay a bit of respect in your reply.
So you did yourself have requested for a real quotation somewhere? Curious to read from it.

Now, if you know a  commercial item that have even half of all the features this one has, then please share with the community, would be fatastic, franky speaking.

kds69, 2021-03-10:
> This is far from an acceptable and fair price. The price is usurious.

I am seriously extremely disappointed by the aggressivity of the reaction of people here.
Unbelievebale !
For sure none of you have spent a minute to look into this project and figure out what budget it is for the components, PCB and then man hours to assemble.
The rapidity of the replies tells a lot anyway...

codingcatgirl, 2021-03-10:
Yes. I'm sure noone in here knows what this repository is about, we are all just random strangers who decided to comment on your post. Absurd accusation.

Anyway, since you indirectly asked for it, here is actually the result of me, weeks ago, spending much more than a minute "to look into this project and figure out what budget it is for the components, PCB". In fact, afterwards, i assembled several ones of them for me and two friends of mine.

Still don't believe me? Here's the octopart BOM i created in the process; https://octopart.com/bom-tool/wTtv413B As you'll see, it indeed adds up to <20$ total per unit, including PCB. (I am curious what component you think costs $14 on it's own already because that's definitely not the experience i've made.)

As for the "and then man hours to assemble.". With a bit of work, you should be able to use JLCPCB's SMT assembly service. They do one SMT assembly order per month per customer for free even, so you only pay for the parts (and small extra costs for parts that aren't in their default parts library). Yes, they will only assemble one side for you, but that will cover a lot. You should be able to get the top side mostly assembled, with the Power Supply and the Relais likely to be missing, but those are Through-Hole Components, so they are easy to solver even if you don't want to touch SMD.

As for the commercial product: Will you really be using all the features at once? All hidden under your light switch? It sounds more likely that you will only be using some of them in each installation. That changes the scope a lot. The main feature of this is after all the mount below a light switch. There are countless products like that available and can easily be found on amazon for $30-50. If you to measure current consumption or control led strips, there are products available for this as well, definitely well below $80.

Point is: Paying $80 for this is pretty absurd and i doubt anyone will be interested in that offer, given how much cheaper you can do it yourself. I hope i was able to help you understand how you should be able to cut your costs if you want to.

kds69, 2021-03-11:
Thank you. This is a much constructive and respectful way to approach it.
I can imagine you are in shock with the price but that is what it is for having it assembled for 5 units only, and I didn’t want to engage in a twice+ bigger batch quantity.

 Very interested to know if those prices are including import taxes and shipping cost?. I really look for total because I received tempting quotes which happens to be way more when you have everything counted.

One of the quickest, but not the cheapest for sure, I kept is PCBWay, for the full service.
Man hours is VERY expensive.

I appreciate the link to this company which I didn’t happen to know. I see this much better price anyway for particular item I mentioned to what I could find (outside sourced by myself to assemble, which also I didn’t want to engage to). Rest is comparable.
Now I am still curious to see what would be the real total price for all full assembly and delivered in less than 4 weeks only, as compared to 14 weeks (which is very acceptable though), including shipping cost and taxes. I will ceh k put and come back with a better offer if by chance it is.

In my case, I can’t afford spend several hours to solder those, nor well equiped, and eventually will ruin it and waste 1 or 2, and not do it in secure manner for use. I’m sure I am not the only one by far. You have this competence, I don’t.

Why didn’t you do what you recommend about commerical items ? I don’t get the point. Do you mean ZipUp commercial item or Zigbee whatever relays, binary sensor etc ? I couldn’t find any commerical version of ZigUp but agin glad to know any.
Indeed, I couldn’t find a commercial item that can do all features I need, taken individually all will be much more expensive, tidious to set-up and maintain and overall too voluminous anyway for my projects.

kds69, 2021-03-11:
Ok it seems JLPCB doesn't provide full assembly services and to get to the low prices , one has to deal with the coupon system. That's the trick. (Still the insourced components are very well priced indeed).
With 10 pieces the PCBWay quote will drop very rapidly apparently, but this is chicken and egg. I can't commit on 10 myself. Still investigating.

codingcatgirl, 2021-03-11:
>Thank you. This is a much constructive and respectful way to approach it.
My first answer was in no way less respectful.

> Why didn’t you do what you recommend about commercial items?
Because ZigUP is cheaper and i like building things myself.

> Do you mean ZipUp commercial item or Zigbee whatever relays, binary sensor etc ?
The latter.

> Ok it seems JLPCB doesn't provide full assembly services and to get to the low prices , one has to deal with the coupon system. That's the trick. (Still the insourced components are very well priced indeed).
They do provide full assembly service for one side of any PCB you make with them. I'm really confused what you mean with "to get the low prices"… i mean after all the base fee is otherwise just $7. Still pretty low. Also, their coupon system usually applies coupons automatically, there isn't really anything you need to do, so there really is no "trick". Delivery is fairly cheap, takes usually about a week to Europe and they take care of customs so you don't need to go through that trouble.

But, yes, if you really want it fully assembled and just put enough money on the counter to have to do no work yourself whatsoever, then it's probably going to be more expensive. I'm afraid to say that this probably doesn't put you at the typical target audience of a DIY hardware project, so you will likely have a hard time finding other people interested in spending that kind of money. Mind you though that since you will need to flash the ZigBee Chip, you will still have to do some work that can be considered hardware work.

kds69, 2021-03-11:
Thanks for the additional information, really.

For occasional DIY like me, even $100 would be a bargain provided the functionality offered by this repository, with a procudred ready-to-go solution, no brainer, no risk (as compared to me soldering and investing in good soldering station).
"where are you even..", "not fair", "usurious"... were probably not the most welcoming and respectful wordings, were they?
Not everybody is looking for the absolute cheapest ever and willing to try electronics DIY, this is what this is about in my case.

I am not an expert of demand-offer in wide spectrum of DIY audience, so I started with what I could come with: 5 items max for max 5 people.
I just posted here, naively, a first proposal to see interest or reactions for people like me.
I'll try to get a better price anyway.

Glad you share your experience and thoughts, this is highly appreciated and I will then have a second look.

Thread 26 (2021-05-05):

ds18b20 not giving measurements

sbruynin, 2021-05-05:
I loaded the latest firmware to a CC2350+2195 but cannot get the temperature sensor to work. I tried router and enddevice firmware and connected a ds18b20 sensor to P0_7.

Zigbee2MQTT:info  2021-05-05 17:38:35: MQTT publish: topic 'zigbee2mqtt/0x00124b001adfb0a3', payload '{"0000000000000000":-999.99,"adc_volt":6.17,"cpu_temperature":10.53,"dig_input":1,"external_humidity":null,"external_temperature":null,"linkquality":0,"reason":"timer","s0_counts":0,"state":"OFF"}'
I can get messages from P1.3 (switch), from P2.0 (dig in) and from timer but not from P0.7

I guess this value pair should be the sensor reading: "0000000000000000":-999.99 or "external_temperature":null
Do I need to configure the ds18b20 elsewhere?

sbruynin, 2021-05-08:
This is a Zbos sniffer output of what I receive from the ZigUP module.
Can somebody give me a hint on where to look in the code to correct the DS28b20 measurement.

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

formtapez, 2021-05-08:
Did you connected the sensor like this?
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

sbruynin, 2021-05-12:
I ordered some E18-MS1 chips to test. I assume the CC2350 with amplifier causes the problem. Somebody some ideas what the difference can be?

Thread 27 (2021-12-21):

Frage Elko 220µ

Titanius, 2021-12-21:
hallo,

welche Aufgabe hat der 220µ/6V3/EEEFK0J221P Elko?

Grüße

formtapez, 2021-12-21:
Der ist zur Spannungsstabilisierung während das Relais umschaltet. Vermutlich könnte es aber auch ein kleinerer sein.

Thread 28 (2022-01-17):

Release pinout

adas4190, 2022-01-17:
Hi. I am curious what pin is assigned to neopixel led in release please. Tahnk You

formtapez, 2022-01-18:
Look at the last picture.
The "LED" Pin. (P1.6 / MOSI)

adas4190, 2022-01-25:
hi thank You for answer. Could you tell me what pin are buttons assigned to please.

Thank You

formtapez, 2022-01-25:
Just look at the schematic.
P1.3 for the main key
P2.0 for alternative key
https://raw.githubusercontent.com/formtapez/ZigUP/master/Layout/Images/schematic.png

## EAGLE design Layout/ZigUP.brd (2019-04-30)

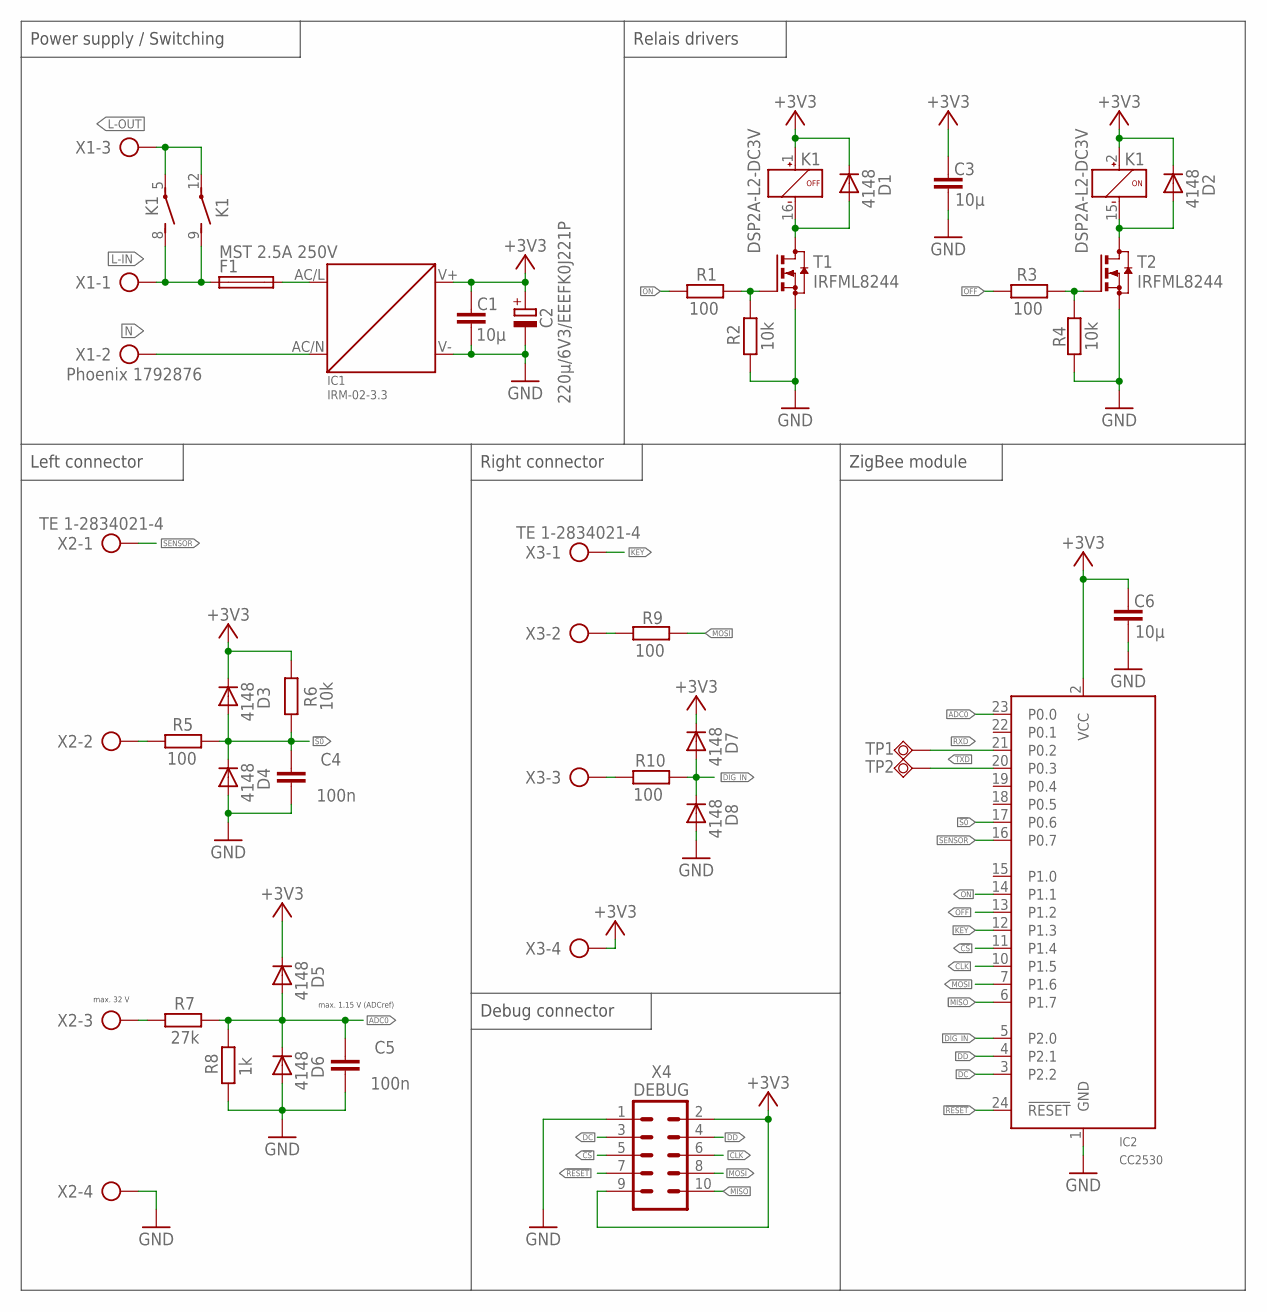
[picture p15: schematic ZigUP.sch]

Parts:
C1, C3, C6: 10µ; C0805
C2: 220µ/6V3/EEEFK0J221P; PANASONIC_D
C4, C5: 100n; C0805
D1, D2, D3, D4, D5, D6, D7, D8: 4148; 1206
F1: MST 2.5A 250V; MST
IC1: IRM-02-3.3; IRM-01
IC2: CC2530; E18-MS1-PCB
K1: DSP2A-L2-DC3V; DSP2A-L2
R1, R3, R5, R9, R10: 100; R0805
R2, R4, R6: 10k; R0805
R7: 27k; R0805
R8: 1k; R0805
T1, T2: IRFML8244; SOT23
TP1: RX; TP15SQ
TP2: TX; TP15SQ
X1: Phoenix 1792876; PTS-3
X2, X3: TE 1-2834021-4; MSC4
X4: DEBUG; MA05-2

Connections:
!CS: IC2.11 (P1.4), X4.5
!RESET: IC2.24 (!RESET), X4.7
!S0: C4.1, D3.A, D4.K, IC2.17 (P0.6), R5.2, R6.1
+3V3: C1.1, C2.+, C3.1, C6.1, D1.K, D2.K, D3.K, D5.K, D7.K, IC1.V+, IC2.2 (VCC), K1.1 (+), K1.2 (+), R6.2, X3.4, X4.2, X4.9
ADC0: C5.1, D5.A, D6.K, IC2.23 (P0.0), R7.2, R8.2
CLK: IC2.10 (P1.5), X4.6
DC: IC2.3 (P2.2), X4.3
DD: IC2.4 (P2.1), X4.4
DIG_IN: D7.A, D8.K, IC2.5 (P2.0), R10.2
GND: C1.2, C2.-, C3.2, C4.2, C5.2, C6.2, D4.A, D6.A, D8.A, IC1.V-, IC2.1 (GND), R2.1, R4.1, R8.1, T1.2 (S), T2.2 (S), X2.4, X4.1
KEY: IC2.12 (P1.3), X3.1
L-FUSED: F1.2, IC1.AC/L
L-IN: F1.1, K1.8 (C), K1.9 (C), X1.1
L-OUT: K1.5 (S), K1.12 (S), X1.3
MISO: IC2.6 (P1.7), X4.10
MOSI: IC2.7 (P1.6), R9.1, X4.8
N: IC1.AC/N, X1.2
unnamed: R7.1, X2.3
unnamed: D2.A, K1.15 (-), T2.3 (D)
unnamed: D1.A, K1.16 (-), T1.3 (D)
unnamed: R3.2, R4.2, T2.1 (G)
unnamed: R1.2, R2.2, T1.1 (G)
unnamed: R5.1, X2.2
unnamed: R9.2, X3.2
unnamed: R10.1, X3.3
OFF: IC2.13 (P1.2), R3.1
ON: IC2.14 (P1.1), R1.1
RXD: IC2.21 (P0.2), TP1.TP
SENSOR: IC2.16 (P0.7), X2.1
TXD: IC2.20 (P0.3), TP2.TP

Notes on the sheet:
max. 1.15 V (ADCref)
max. 32 V
Power supply / Switching
Relais drivers
Left connector
Right connector
Debug connector
ZigBee module

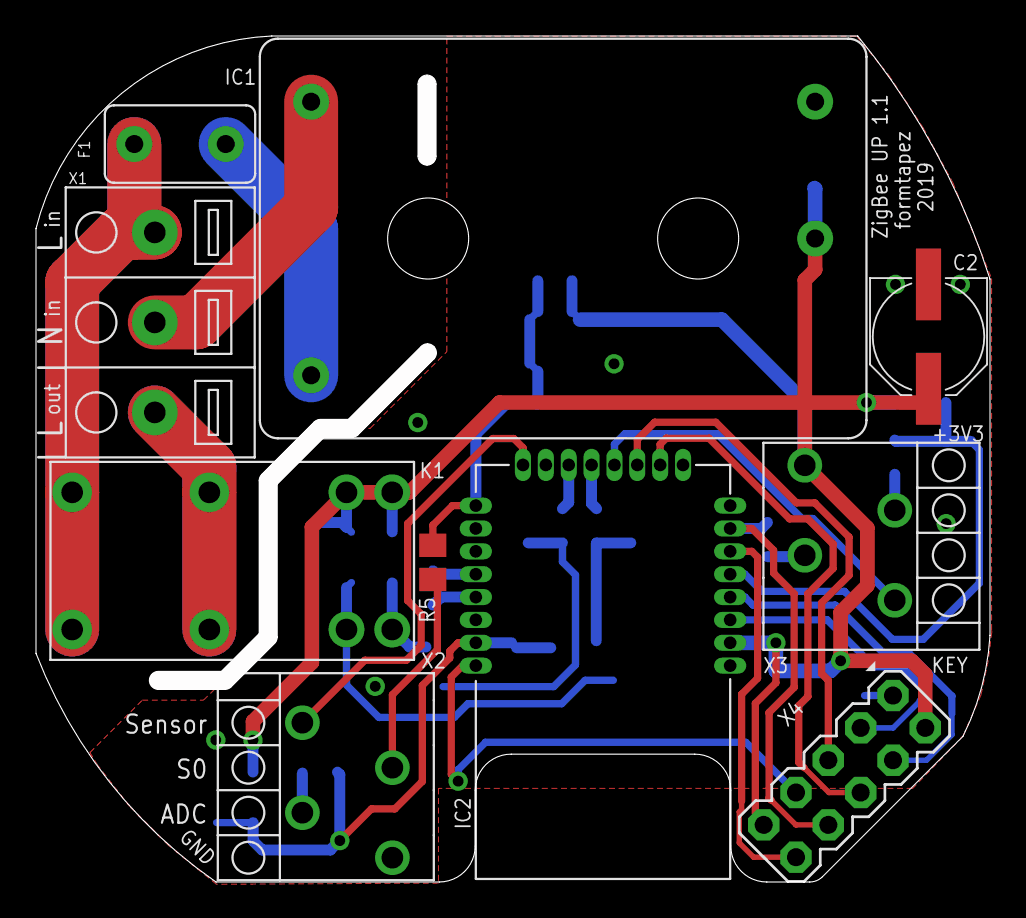
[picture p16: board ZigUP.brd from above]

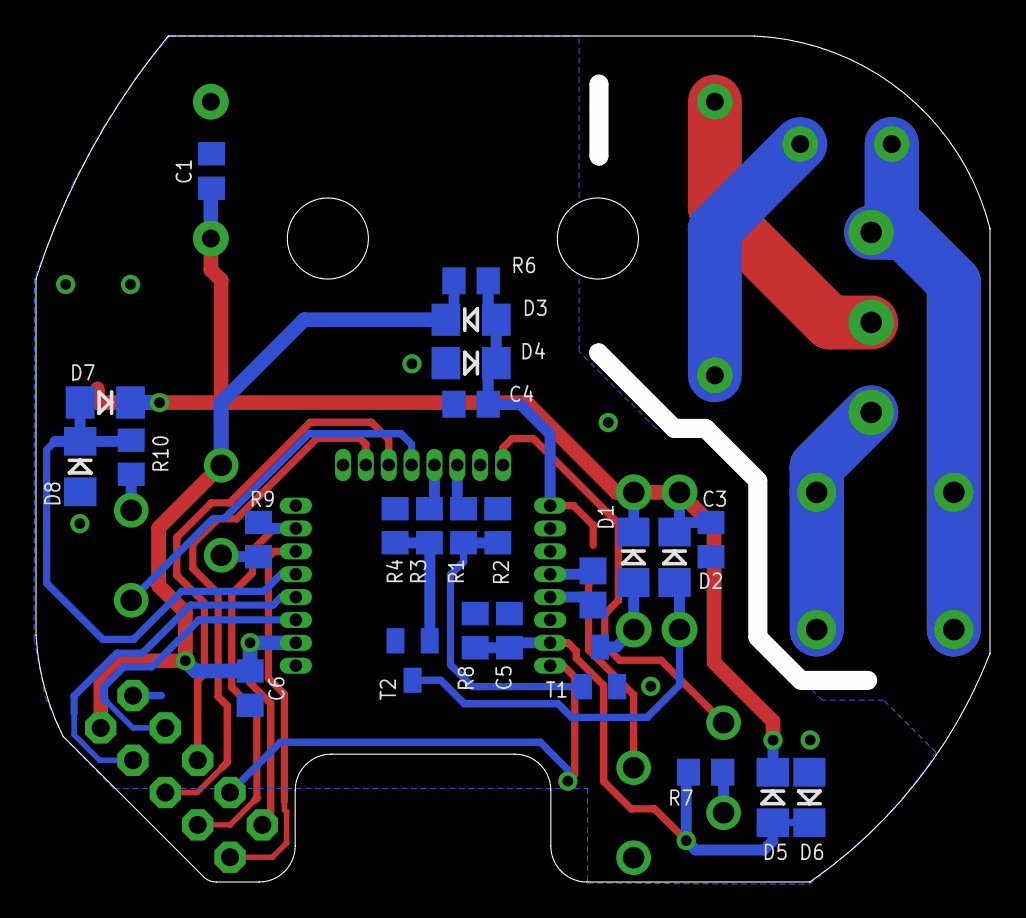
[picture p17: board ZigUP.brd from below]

Board: 2 copper layers, 53.0 x 47.0 mm, 36 parts (26 on the bottom side), 30 nets.

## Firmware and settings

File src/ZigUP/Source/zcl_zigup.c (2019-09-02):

#include <stdlib.h>
#include <string.h>
#include <stdio.h>
#include <math.h>

#include "zcl_lighting.h"
#include "zcl_closures.h"
#include "zcl_zigup.h"
#include "zcl.h"
#include "zcl_ha.h"
#include "zcl_diagnostic.h"

#include "onboard.h"
#include "ZDSecMgr.h"
#include "bitmasks.h"
#include "delay.h"
#include "ds18b20.h"
#include "uart.h"
#include "global.h"
#include "adc.h"
#include "random.h"
#include "ws2812.h"
#include "interrupts.h"
#include "led.h"
#include "dht22.h"
#include "utils.h"

#define ZIGUP_REPORTING_INTERVAL 30000

afAddrType_t zclZigUP_DstAddr;

// Test Endpoint to allow SYS_APP_MSGs
static endPointDesc_t ZigUP_TestEp =
{
  ZIGUP_ENDPOINT,
  &zclZigUP_TaskID,
  (SimpleDescriptionFormat_t *)NULL,  // No Simple description for this test endpoint
  (afNetworkLatencyReq_t)0            // No Network Latency req
};

devStates_t zclZigUP_NwkState = DEV_INIT;

void zclZigUP_Reporting(uint16 REPORT_REASON)
{
  const uint8 NUM_ATTRIBUTES = 9;
  
  // send report
  zclReportCmd_t *pReportCmd;
  
  pReportCmd = osal_mem_alloc( sizeof(zclReportCmd_t) + ( NUM_ATTRIBUTES * sizeof(zclReport_t) ) );
  if ( pReportCmd != NULL )
  {
    pReportCmd->numAttr = NUM_ATTRIBUTES;
    
    pReportCmd->attrList[0].attrID = ATTRID_ON_OFF;
    pReportCmd->attrList[0].dataType = ZCL_DATATYPE_BOOLEAN;
    pReportCmd->attrList[0].attrData = (void *)(&STATE_LIGHT);
    
    pReportCmd->attrList[1].attrID = ATTRID_CPU_TEMP;
    pReportCmd->attrList[1].dataType = ZCL_DATATYPE_SINGLE_PREC;
    pReportCmd->attrList[1].attrData = (void *)(&CPU_Temperature);
    
    pReportCmd->attrList[2].attrID = ATTRID_EXT_TEMP;
    pReportCmd->attrList[2].dataType = ZCL_DATATYPE_SINGLE_PREC;
    pReportCmd->attrList[2].attrData = (void *)(&EXT_Temperature);
    
    pReportCmd->attrList[3].attrID = ATTRID_EXT_HUMI;
    pReportCmd->attrList[3].dataType = ZCL_DATATYPE_SINGLE_PREC;
    pReportCmd->attrList[3].attrData = (void *)(&EXT_Humidity);
    
    pReportCmd->attrList[4].attrID = ATTRID_S0_COUNTS;
    pReportCmd->attrList[4].dataType = ZCL_DATATYPE_UINT32;
    pReportCmd->attrList[4].attrData = (void *)(&S0);
    
    pReportCmd->attrList[5].attrID = ATTRID_ADC_VOLT;
    pReportCmd->attrList[5].dataType = ZCL_DATATYPE_SINGLE_PREC;
    pReportCmd->attrList[5].attrData = (void *)(&ADC_Voltage);
    
    pReportCmd->attrList[6].attrID = ATTRID_DIG_INPUT;
    pReportCmd->attrList[6].dataType = ZCL_DATATYPE_UINT16; // boolean or uint8 causes every second report to hang...
    pReportCmd->attrList[6].attrData = (void *)(&DIG_IN);

    pReportCmd->attrList[7].attrID = ATTRID_REPORT_REASON;
    pReportCmd->attrList[7].dataType = ZCL_DATATYPE_UINT16;
    pReportCmd->attrList[7].attrData = (void *)(&REPORT_REASON);
 
    pReportCmd->attrList[8].attrID = ATTRID_EXT_TEMPS;
    pReportCmd->attrList[8].dataType = ZCL_DATATYPE_CHAR_STR;
    pReportCmd->attrList[8].attrData = (void *)(&EXT_Temperature_string);
   
      
    zclZigUP_DstAddr.addrMode = (afAddrMode_t)Addr16Bit;
    zclZigUP_DstAddr.addr.shortAddr = 0;
    zclZigUP_DstAddr.endPoint=1;
    
    zcl_SendReportCmd( ZIGUP_ENDPOINT, &zclZigUP_DstAddr, ZCL_CLUSTER_ID_GEN_ON_OFF, pReportCmd, ZCL_FRAME_CLIENT_SERVER_DIR, false, zclZigUPSeqNum++ );
  }
  
  osal_mem_free( pReportCmd );
}


/*********************************************************************
* ZCL General Profile Callback table
*/
static zclGeneral_AppCallbacks_t zclZigUP_CmdCallbacks =
{
  zclZigUP_BasicResetCB,                  // Basic Cluster Reset command
  zclZigUP_IdentifyCB,                    // Identify command
  NULL,                                   // Identify Trigger Effect command
  zclZigUP_IdentifyQueryRspCB,            // Identify Query Response command
  zclZigUP_OnOffCB,                       // On/Off cluster commands
  NULL,                                   // On/Off cluster enhanced command Off with Effect
  NULL,                                   // On/Off cluster enhanced command On with Recall Global Scene
  NULL,                                   // On/Off cluster enhanced command On with Timed Off
#ifdef ZCL_GROUPS
  NULL,                                   // Group Response commands
#endif
#ifdef ZCL_SCENES
  NULL,                                   // Scene Store Request command
  NULL,                                   // Scene Recall Request command
  NULL,                                   // Scene Response command
#endif
#ifdef ZCL_ALARMS
  NULL,                                   // Alarm (Response) commands
#endif
#ifdef SE_UK_EXT
  NULL,                                   // Get Event Log command
  NULL,                                   // Publish Event Log command
#endif
  NULL,                                   // RSSI Location command
  NULL                                    // RSSI Location Response command
};

static zclLighting_AppCallbacks_t zclZigUP_LightingCmdCBs =
{
  NULL,                         // Move To Hue Command
  NULL,                         // Move Hue Command
  NULL,                         // Step Hue Command
  NULL,                         // Move To Saturation Command
  NULL,                         // Move Saturation Command
  NULL,                         // Step Saturation Command
  NULL,                         // Move To Hue And Saturation  Command
  zclZigUP_MoveToColorCB,       // Move To Color Command
  NULL,                         // Move Color Command
  NULL,                         // STEP To Color Command
  NULL,                         // Move To Color Temperature Command
  NULL,                         // Enhanced Move To Hue
  NULL,                         // Enhanced Move Hue;
  NULL,                         // Enhanced Step Hue;
  NULL,                         // Enhanced Move To Hue And Saturation;
  NULL,                         // Color Loop Set Command
  NULL,                         // Stop Move Step;
};

static zclClosures_DoorLockAppCallbacks_t zclZigUP_DoorLockCmdCallbacks =
{
  zclZigUP_DoorLockCB,                           // DoorLock cluster command
  zclZigUP_DoorLockRspCB,                        // DoorLock Response
  NULL,
  NULL,
  NULL,
  NULL,
  NULL,
  NULL,
  NULL,
  NULL,
  NULL,
  NULL,
  NULL,
  NULL,
  NULL,
  NULL,
  NULL,
  NULL,
  NULL,
  NULL,
  NULL,
  NULL,
  NULL,
  NULL,
  NULL,
  NULL,
  NULL,
  NULL,
  NULL,
  NULL,
  NULL,
  NULL,
  NULL,
  NULL,
  NULL,
  NULL,
  NULL,
  NULL,
  NULL,
  NULL,
  NULL,
  NULL,
  NULL,
  NULL,
  NULL,
  NULL,
  NULL,
  NULL,
  NULL,
  NULL
};
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

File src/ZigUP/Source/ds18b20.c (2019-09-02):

#include <stdio.h>
#include "onboard.h"
#include "ZComDef.h"
#include "bitmasks.h"
#include "delay.h"
#include "ds18b20.h"
#include "uart.h"
#include "global.h"
#include "hal_mcu.h"


#define DS18B20_SKIP_ROM 		0xCC
#define DS18B20_CONVERT_T 		0x44
#define DS18B20_MATCH_ROM               0x55
#define DS18B20_SEARCH_ROM		0XF0
#define DS18B20_READ_SCRATCHPAD         0xBE
#define DS18B20_WRITE_SCRATCHPAD        0x4E
#define DS18B20_COPY_SCRATCHPAD         0x48


// Sends one bit to bus
void ds18b20_send_bit(uint8 bit, uint8 useInterrupts)
{
  P0_7 = 1;
  if (useInterrupts)
    HAL_DISABLE_INTERRUPTS();
  P0DIR |= (1<<7);     // output
  P0_7 = 0;
  if ( bit != 0 ) 
    _delay_us( 8 );
  else 
    _delay_us( 80 );
  P0_7 = 1;
  if (useInterrupts)
    HAL_ENABLE_INTERRUPTS();   
  if ( bit != 0 ) 
    _delay_us( 80 );
  else 
    _delay_us( 2 );
  
//  if (bit==1) P0_7 = 1;
//  _delay_us(100);
//  P0_7 = 1;
}


// Reads one bit from bus
uint8 ds18b20_read_bit(uint8 useInterrupts)
{
  uint8 i;
 
  
  P0_7 = 1;
  if (useInterrupts)
    HAL_DISABLE_INTERRUPTS();
  P0DIR |= (1<<7);     // output
  P0_7 = 0;
  _delay_us(2);
//  P0_7 = 1;
//  _delay_us(15);
  P0DIR &= ~(1<<7);     // input
  _delay_us( 5 );
  i = P0_7;
  if (useInterrupts)
    HAL_ENABLE_INTERRUPTS();
  _delay_us( 60 );
  return i;
}


// Sends one byte to bus
void ds18b20_send_byte(int8 data, uint8 useInterrupts)
{
  uint8 i,x;
  for(i=0;i<8;i++)
  {
    x = data>>i;
    x &= 0x01;
    ds18b20_send_bit(x, useInterrupts);
  }
  //_delay_us(100);
}


// Reads one byte from bus
uint8 ds18b20_read_byte(uint8 useInterrupts)
{
  uint8 i;
  uint8 data = 0;
  for (i=0;i<8;i++)
  {
    if(ds18b20_read_bit(useInterrupts)) data|=0x01<<i;
    //_delay_us(25);
  }
  return(data);
}


// Sends reset pulse
uint8 ds18b20_RST_PULSE(void)
{
  uint8 i;
  P0_7 = 0;
  P0DIR |= (1<<7);     // output
  _delay_us(600);
  P0DIR &= ~(1<<7);     // input
  _delay_us(70);
  i = P0_7;
  _delay_us(200);
  P0_7 = 1;
  P0DIR |= (1<<7);     // output
  _delay_us(600);
  return i;
}


//////////////////////////////////////////////////////////////////////////////
// ONE WIRE CRC
//
uint8 ds18b20_ow_crc( uint8 x)
{
  ds18b20_dowcrc = ds18b20_dscrc_table[ds18b20_dowcrc^x];
  return ds18b20_dowcrc;
}


// NEXT
// The Next function searches for the next device on the 1-Wire bus. If
// there are no more devices on the 1-Wire then false is returned.
//
uint8 ds18b20_Next(void)
{
  uint8 m = 1; // ROM Bit index
  uint8 n = 0; // ROM Byte index
  uint8 k = 1; // bit mask
  uint8 x = 0;
  uint8 discrepMarker = 0; // discrepancy marker
  uint8 g; // Output bit
  uint8 nxt; // return value
  int flag;
  
  nxt = FALSE; // set the next flag to false
  ds18b20_dowcrc = 0; // reset the dowcrc
  flag = ds18b20_RST_PULSE(); // reset the 1-Wire
  if(flag|| ds18b20_doneFlag) // no parts -> return false
  {
    ds18b20_lastDiscrep = 0; // reset the search
    return FALSE;
  }
  ds18b20_send_byte(0xF0, 0); // send SearchROM command
  do
    // for all eight bytes
  {
    x = 0;
    if(ds18b20_read_bit(0)==1) 
      x = 2;
    _delay_us(15);
    if(ds18b20_read_bit(0)==1) 
      x |= 1; // and its complement
    if(x ==3) // there are no devices on the 1-Wire
      break;
    else
    {
      if(x>0) // all devices coupled have 0 or 1
        g = x>>1; // bit write value for search
      else
      {
        // if this discrepancy is before the last
        // discrepancy on a previous Next then pick
        // the same as last time
        if(m<ds18b20_lastDiscrep)
          g = ((ds18b20_ROM[n]&k)>0);
        else // if equal to last pick 1
          g = (m==ds18b20_lastDiscrep); // if not then pick 0
        // if 0 was picked then record
        // position with mask k
        if (g==0) 
          discrepMarker = m;
      }
      if(g==1) // isolate bit in ROM[n] with mask k
        ds18b20_ROM[n] |= k;
      else
        ds18b20_ROM[n] &= ~k;
      ds18b20_send_bit(g, 0); // ROM search write
      m++; // increment bit counter m
      k = k<<1; // and shift the bit mask k
      if(k==0) // if the mask is 0 then go to new ROM
      { // byte n and reset mask
        ds18b20_ow_crc(ds18b20_ROM[n]); // accumulate the CRC
        n++; k++;
      }
    }
  }while(n<8); //loop until through all ROM bytes 0-7
  
  if(m<65||ds18b20_dowcrc) // if search was unsuccessful then
    ds18b20_lastDiscrep=0; // reset the last discrepancy to 0
  else
  {
    // search was successful, so set lastDiscrep,
    // lastOne, nxt
    ds18b20_lastDiscrep = discrepMarker;
    ds18b20_doneFlag = (ds18b20_lastDiscrep==0);
    nxt = TRUE; // indicates search is not complete yet, more
    // parts remain
  }
  return nxt;
}


// FIRST
// The First function resets the current state of a ROM search and calls
// Next to find the first device on the 1-Wire bus.
//
uint8 ds18b20_First(void)
{
  ds18b20_lastDiscrep = 0; // reset the rom search last discrepancy global
  ds18b20_doneFlag = FALSE;
  return ds18b20_Next(); // call Next and return its return value
}


uint8 ds18b20_find_devices(void)
{
  unsigned char m;
  ds18b20_numROMs=0;
  char buffer[100];
  
  if(!ds18b20_RST_PULSE()) //Begins when a presence is detected
  {
    if(ds18b20_First()) //Begins when at least one part is found
    {
      do
      {
        for(m=0;m<8;m++)
        {
          ds18b20_FoundROM[ds18b20_numROMs][m] = ds18b20_ROM[m]; //Identifies ROM
        } 
        sprintf(buffer, "Sensor %d ROM CODE = %02X%02X%02X%02X%02X%02X%02X%02X",  ds18b20_numROMs,
                ds18b20_FoundROM[ds18b20_numROMs][7],ds18b20_FoundROM[ds18b20_numROMs][6],ds18b20_FoundROM[ds18b20_numROMs][5],ds18b20_FoundROM[ds18b20_numROMs][4],
                ds18b20_FoundROM[ds18b20_numROMs][3],ds18b20_FoundROM[ds18b20_numROMs][2],ds18b20_FoundROM[ds18b20_numROMs][1],ds18b20_FoundROM[ds18b20_numROMs][0]);
        UART_String(buffer);
        ds18b20_numROMs++;
      }while (ds18b20_Next()&&(ds18b20_numROMs<ds18b20_MAX_DEVICES+1)); //Continues until no additional devices are found
    }
  }
  return ds18b20_numROMs;
}


void ds18b20_start_conversion(void)
{
  if(!ds18b20_RST_PULSE())
  {
    ds18b20_send_byte(DS18B20_SKIP_ROM, 1);
    ds18b20_send_byte(DS18B20_CONVERT_T, 1);
    _delay_ms(750);
  }
}


void ds18b20_SelectSensor(uint8 ID)
{
  uint8 i;
  
  if(!ds18b20_RST_PULSE())
  {
    ds18b20_send_byte(DS18B20_MATCH_ROM, 1); // DS18B20_MATCH_ROM
    for(i=0;i<8;i++)
    {
      ds18b20_send_byte(ds18b20_FoundROM[ID][i], 1); //send ROM code
    }
  }
}
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

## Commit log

2019-04-30 added hardware related files
    [ZigUP.GBL, ZigUP.GBO, ZigUP.GBS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]
2019-05-04 implemented LED control
2019-05-05 sensor autodetection
2019-05-10 added report-reason, removed non-router configurations, sensor checks
2019-05-18 Fixed LED-Control
2019-05-19 added BOM
2019-08-21 Added support for 16 ds18b16 temperature sensors
2019-08-31 removed debouncing for S0-pulse to not loose it on nested interrupts
    [interrupts.c]
